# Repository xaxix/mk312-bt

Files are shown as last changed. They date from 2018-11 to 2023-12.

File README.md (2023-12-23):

# MK-312BT V1.3

Documentation at : http://tinyurl.com/mk312bt-info

Forum (for questions/discussion): https://metafetish.club ([Estim
Specific Category Here](https://metafetish.club/c/estim), but may not
include all estim messages)

## Board ordering instructions

Preferred board house is https://jlcpcb.com

You'll need 2 gerber zip files from the gerbers directory (click links below to download):

- [MK-312 V1.2 Front Panel](https://github.com/buttshock/mk312-bt/blob/master/gerbers/ZIP%20FILES/MK-312BT%20Front%20Panel%20V1.2%20Gerber.zip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)
- [MK-312 V1.3 Main Board](https://github.com/buttshock/mk312-bt/blob/master/gerbers/ZIP%20FILES/MK-312BT%20Main%20Boards%20V1.3%20Gerber.zip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)

**NOTE:** Order Front Panel and Main Board as seperate items (but they
can be in the same cart), due to difference in "Different Design"
setting. See below.

- Base Material: Standard "FR4"
- Layers: "2" Layer (should be detected when you upload the zip with the gerbers)
- Dimensions: (should be detected when you upload the zip with the gerbers)
- Quantity: No requirement, choose whatever you like
- Product Type: "Industrial/Consumer electronics"
- Different Design 
   - Main Boards: "2"
   - Front Panel: "1"
- Delivery Format: "Single PCB"
- Thickness: "1.6"
- PCB Color:
   - Main Boards: No requirement, choose whatever you like
   - Front Panel: Black is recommended, but not required. Choose whatever you like otherwise.
- Silkscreen: "White"
- Surface finish: "LeadFree HASL" or "HASL(with lead)
- Copper weight: 1oz
- Via Covering: Tented (?)
- Board Outline Tolerance: "+-0,2mm(Regular)"
- Confirm Production file: "No"
- Remove Order Number: "No"
- Flying Probe Test: "Fully Test"
- Gold fingers: "No"
- Castellated Holes: "No"
- Edge Plating: "No"
- PCB Remark:
   - Main Boards: V Score the Main Boards panel as indicated.
   - Front Panel: Place all Fab Markings (Serial Numbers/Date Codes) on the BOTTOM side of the front panel board.
   
## Board Assembly Instructions - IMPORTANT

1. Trim Potentiometer knobs to correct length if desired
2. Use black permanent marker to black out front panel hole walls if
   desired
3. Cut the tabs off of the base of the pots so the board sits flush
   with the display facade if desired
4. To correctly fit LCD - solder header to LCD board first. Next
   insert LCD panel into front panel daughter board. Then put screws
   on front panel facade and finger tighten M2.5 screws first. Adjust
   positions as needed so everything lines up and sits well. Finally
   solder LCD header to front panel daughter board.
5. Make sure Pin 32 (LED2) on the HC-05 module is actually soldered
   and making connection to the ZS-040 break out board or "Radio" LED
   may not function on the front panel
6. Be very careful not to bridge pins when soldering the LM 2941
   (U14). Apply heat to 1 pad only and carefully apply solder. If a
   bridge occurs - remove the IC, clean the pads throughly with flux
   and solder wick and then retry. Pins 2 and 3 can be bridged because
   they are both ground. Ensure that no other pins are bridged. Check
   with multimeter continuity tester for bridges before power on!
7. Make sure to check the orientation of all electrolytic caps. (+)
   indicates the positive and a solid white "|" indicates the negative.
8. **MAKE SURE YOUR POWER PLUG IS CENTER POSITIVE OR THINGS WILL GO
   BADLY.** If you fuck up and plug in a reversed polarity supply -
   replace electrolytic caps C1 and C4.
9. Please remember to adjust the LCD contrast potentiometer - if
   incorrectly set the unit and backlight will power on but the
   interface will not be displayed.
10. Place transformers with P facing the output jacks (yes we are
    using the transformers "backwards" if you follow orientation given
    in the transformer datasheet )
11. Trim pins of 4066 IC (U3) Socket on the front panel board flush
    before soldering so buttons can clear. If the buttons still
    interfere, carefully disassemble the button and cut off the bit of
    the plastic housing that interferes with the 4066 IC socket pins.
12. Using side cutters cut off the screw boss/screw mount on the case
    that touches/interferes with the ribbon cable socket on the
    display board.
13. The LCD display has metal retention tabs that may short the
    soldered leads of C43. When installing the display board ensure
    that this does not happen (shorten the capacitor leads and bend
    the offending metal tab out of the way if necessary
14. If Error 20 is encountered on first boot:
   - Check that all FETs and Transformers are turned in the correct direction
   - Check that resistors R35 and R46 are the correct 200k values
   - [See this thread on the message board](https://metafetish.club/t/mk-312bt-failure-20/)

## MK312-BT Firmware

1. We are using an external 8mhz crystal instead of the internal RC
   oscillator that the original uses. We need to set the fuses to
   enable this. 
   - LOW FUSE: 0xFF 
   - HIGH FUSE: 0xDC
2. A patched version of buttshock-et312-frankenbutt-f005 is
   recommended.
3. The firmware needs to be changed to replace the up/down arrows on
   the UI with left right arrows (this is because the LCD we use has a
   different character set)
4. Obtain or modify a copy of the firmware and flash the result onto
   the AVR.
5. If you don't want to use an external crystal - we need to set the
   calibration byte for the internal oscillator. If programming a
   blank chip you first need to read the calibration bytes of that
   part (i.e. using avrdude -t “dump calibration” the fourth byte is
   the calibration byte for 8MHz or use atmel studio to read the
   oscillator calibration byte). Then program that byte into 0x3fff in
   your firmware. These bytes will differ on different chips even from
   the same batch. The firmware reads that byte to set OSCCAL on
   startup. If the byte is inaccurate various problems and failures
   will occur related to timing, interrupts, and serial communication.
   Just use an external crystal dammit.

## MK312-BT Original Fab Notes

(These are the old fab notes from the repo, mostly kept here for
history sake. Ordering instructions above cover most of this.)

### Main Boards

1. V Score the Main Boards panel as indicated.
2. Main Boards has 2 board designs panelized on 1 panel.
3. Thickness is standard 1.6mm (0.063inches)
4. Board is 2 layers
5. HASL Finish - Pb Free Preferred if possible, otherwise Pb HASL is OK
6. 1oz copper
7. FR4 material
8. Main Boards : Green solder mask, White Silkscreen (silkscreen BOTH top and bottom sides)
9. ITAR : NO
10. IPC-A-610 - Class2 (If possible - otherwise ignore)
11. Main Board Dimensions : (193.04mm x 104.14mm) or (7.600 inches x 4.100 inches) 

### Front Panel Boards

1. Place all Fab Markings (Serial Numbers/Date Codes) on the BOTTOM side of the front panel board. 
2. Thickness is standard 1.6mm (0.063inches)
3. Board is 2 layers
4. HASL Finish - Pb Free Preferred if possible, otherwise Pb HASL is OK
5. 1oz copper
6. FR4 material
7. Front Panel Boards : Black Solder Mask, While Silkscreen
8. ITAR : NO
9. IPC-A-610 - Class2 (If possible - otherwise ignore)
10. Front Panel Board Dimensions :  (196.85mm x 58.72mm) or (7.750inches x 2.312inches) 

## Bluetooth Serial Configuration

Refer to
[https://www.itead.cc/wiki/Serial_Port_Bluetooth_Module_(Master/Slave)_:_HC-05](https://www.itead.cc/wiki/Serial_Port_Bluetooth_Module_(Master/Slave)_:_HC-05)
for more information.

```
// Test command to check if we are communicating (expect to receive OK)
AT

//Name the module
AT+NAME=MK-312BT 

//Set baud rate to be same as the ATMEGA16
AT+UART=19200,0,0

//Set the pairing password
AT+PSWD=1234

//Set the LED Indicator polarity (1 = High Drive 0 = Low Drive)
AT+POLAR=1,1

// Reduce power consumption by increasing the scan interval. Without
// this it consumes ~43mA when not connected and causes the 5v regulator
// to get toasty (but still within operational temp range)
AT+IPSCAN=1024,1,1024,1 
```

To do this automatically:
1. Solder Pin32 of the HC05 module (See [bluetooth/HC05PINOUT.PNG](https://github.com/buttshock/mk312-bt/blob/master/bluetooth_conf/HC05PINOUT.png) for reference)
2. Flash the included bin file onto the ATMEGA16
3. Plug the HC-05 bluetooth radio into the board (ensure pin 32 is
   soldered to the carrier board)
4. Place HC-05 in command mode by holding down the button on the HC-05
   module, power up MK-312BT and release button after 2 seconds. LEDs
   on HC-05 will blink slowly (0.5 Hz) to indicate command mode.
5. Watch GUI until it says the HC-05 configuration is finished and
   flash normal firmware back on to the ATMEGA16
6. If program stops on "Communicating with HC-05" make sure OSCCAL
   value for 8 MHz R/C position is copied to &H3FFF of bin location or
   use external 8 MHz crystal with appropriate fuse bits set (FFS use
   the external crystal)

## 3D Printable Case

STL files for a 3D printable case for the MK312 are available in the
case/ directory. For hardware, this case requires:

- 4 M2.5x20 screws
- up to 3 M2.5x5 screws
- some dampening for the battery (double sided foam tape may work)

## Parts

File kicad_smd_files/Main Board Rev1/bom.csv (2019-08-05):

Item | Qty | Reference(s) | Value | LibPart | Footprint | Datasheet | Allied Price/Stock | Allied_Number | Description | Height | Manufacturer_Name | Manufacturer_Part_Number | Mouser Part Number | Mouser Price/Stock | Notes | RS Part Number | RS Price/Stock
1 | 1 | C1 | 10uF | Device:C_Small | Capacitor_SMD:C_0805_2012Metric |  |  |  |  |  | Taiyo Yuden | TMK212BBJ106MG-T | 963-TMK212BBJ106MG-T
2 | 27 | C2, C3, C6, C7, C8, C9, C10, C11, C17, C18, C19, C20, C24, C31, C34, C35, C36, C37, C40, C41, C42, C43, C44, C45, C46, C47, C48 | 0.1uF | Device:C_Small | Capacitor_SMD:C_0402_1005Metric | https://www.mouser.com/datasheet/2/281/murata_03122018_GCM_Series-1310150.pdf |  |  |  |  | Murata | GCM155R71C104JA55D | 81-GCM155R71C104JA5D
3 | 2 | C4, C5 | 100uF | Device:CP1 | Capacitor_SMD:C_Elec_6.3x7.7 | https://www.mouser.com/datasheet/2/315/ABA0000C1240-1130326.pdf |  |  |  |  | Panasonic | EEE-HC1C101XP | 667-EEE-HC1C101XP
4 | 2 | C12, C14 | 470uF | Device:CP1 | Capacitor_SMD:C_Elec_8x10.2 | https://www.mouser.com/datasheet/2/315/ABA0000C1181-947564.pdf |  |  |  |  | Panasonic | EEE-FK1C471P | 667-EEE-FK1C471P
5 | 1 | C13 | 10uF | Device:CP1 | Capacitor_SMD:C_Elec_4x5.8 | https://www.mouser.com/datasheet/2/315/ABA0000C1181-947564.pdf |  |  |  |  | Panasonic | EEE-FK1C100R | 667-EEE-FK1C100R
6 | 2 | C15, C16 | 18pF | Device:C_Small | Capacitor_SMD:C_0402_1005Metric | https://www.mouser.com/datasheet/2/281/GCM1555C1H180FA16-01-1064431.pdf |  |  |  |  | Murata | GCM1555C1H180FA16J | 81-GCM1555C1H180FA6J
7 | 11 | C21, C22, C23, C25, C26, C27, C28, C29, C30, C38, C39 | 1uF | Device:C_Small | Capacitor_SMD:C_0402_1005Metric | https://www.mouser.com/datasheet/2/281/murata_03052018_GRM_Series_1-1310166.pdf |  |  |  |  | Murata | GRM155R61C105MA12D | 81-GRM155R61C105MA2D
8 | 2 | C32, C33 | 1nF | Device:C_Small | Capacitor_SMD:C_0402_1005Metric | https://www.mouser.com/datasheet/2/281/murata_03122018_GCM_Series-1310150.pdf |  |  |  |  | Murata | GCM1555C1H102JA16J | 81-GCM1555C1H102JA6J
9 | 1 | C49 | 2.2uF | Device:C_Small | Capacitor_SMD:C_0603_1608Metric |  |  |  |  |  | KEMET | C0603C225K4PACTU | 80-C0603C225K4P
10 | 2 | D1, D2 | GF1G-E3/67A | Diode:1N4004 | mk312-smd-footprints:DO-214BA | http://www.rectron.com/public/product_datasheets/fm4001w-fm4007w.pdf |  |  | Rectifiers 1A, 400V | 2.31 | Rectron | FM4004W-W | 583-FM4004W-W | https://www.mouser.com/Search/Refine.aspx?Keyword=583-FM4004W-W
11 | 2 | D3, D4 | 1N4148W-E3-08 | Device:D | Diode_SMD:D_SOD-123 | https://www.mouser.com/datasheet/2/427/1n4148w-240387.pdf |  |  |  |  | Vishay | 1N4148W-E3-08 | 78-1N4148W-E3-08
12 | 1 | F1 | 1A Polyfuse | Device:Polyfuse | Fuse:Fuse_2920_7451Metric | https://www.mouser.com/datasheet/2/643/0ZCF_Nov2016-1133542.pdf |  |  |  |  | Bel Fuse | 0ZCF0100AF2A | 530-0ZCF0100AF2A
13 | 6 | H1, H2, H3, H4, H5, H6 | MountingHole | Mechanical:MountingHole | MountingHole:MountingHole_2.7mm_M2.5 | ~
14 | 2 | H7, H8 | MountingHole | Mechanical:MountingHole | MountingHole:MountingHole_3.5mm | ~
15 | 1 | IC1 | LMS8117ADTX-ADJ | Regulator_Linear:NCP1117-ADJ_TO252 | Package_TO_SOT_SMD:TO-252-2 | www.ti.com/lit/ds/symlink/lms8117a.pdf |  |  |  |  | Texas Instruments | LMS8117ADTX-ADJ | 926-LS8117ADTXADJNPB
16 | 1 | IC2 | L7805CV | Regulator_Linear:L7805 | Package_TO_SOT_THT:TO-220-3_Vertical | https://www.mouser.com/datasheet/2/389/l78-974043.pdf | http://www.alliedelec.com/stmicroelectronics-l7805abd2t-tr/70407657/ | 70407657 |  | 4.6 | STMicroelectronics | L7805CV | 511-L7805CV | https://www.mouser.com/Search/Refine.aspx?Keyword=511-L7805ABD2T-TR |  | 7931342P | http://uk.rs-online.com/web/p/products/7931342P
17 | 2 | IC3, IC4 | L7809ABV | Regulator_Linear:L7809 | Package_TO_SOT_THT:TO-220-3_Vertical | https://www.mouser.com/datasheet/2/389/l78-974043.pdf |  |  |  |  | STMicroelectronics | L7809ABV | 511-L7809ABV | https://www.mouser.com/Search/Refine.aspx?Keyword=511-L7809ABD2T-TR
18 | 2 | IC5, IC6 | SI4435FDY-T1-GE3 | SamacSys_Parts:SI4435FDY-T1-GE3 | mk312-smd-footprints:SOIC127P600X175-8N | http://www.vishay.com/docs/75339/si4435fdy.pdf |  |  | MOSFET -30V Vds 20V Vgs SO-8 | 1.75 | Vishay | SI4435FDY-T1-GE3 | 78-SI4435FDY-T1-GE3 | https://www.mouser.com/Search/Refine.aspx?Keyword=78-SI4435FDY-T1-GE3
19 | 1 | J1 | Barrel_Jack_MountingPin | Connector:Barrel_Jack_Switch | Connector_BarrelJack:BarrelJack_Horizontal | https://www.mouser.com/datasheet/2/670/pj-002a-1312176.pdf |  |  |  |  | CUI | PJ-002A | 490-PJ-002A
20 | 1 | J2 | +12V Battery | Connector_Generic:Conn_01x02 | Connector_AMASS:AMASS_XT30U-M_1x02_P5.0mm_Vertical | ~
21 | 1 | J3 | Conn_02x03_Odd_Even | Connector_Generic:Conn_02x03_Odd_Even | Connector_PinHeader_2.54mm:PinHeader_2x03_P2.54mm_Vertical | https://www.mouser.com/datasheet/2/418/NG_CD_103328_P5-1229876.pdf |  |  |  |  | TE Connectivity / AMP | 4-103328-2 | 571-4-103328-2
22 | 1 | J4 | RADIO INTERFACE | Connector_Generic:Conn_01x06 | Connector_PinHeader_2.54mm:PinHeader_1x06_P2.54mm_Vertical | https://www.mouser.com/datasheet/2/527/slw-1370256.pdf |  |  |  |  | Samtec | SLW-106-01-G-S | 200-SLW10601GS
23 | 1 | J5 | MIC INPUT | Connector:AudioJack3_SwitchTR | mk312-smd-footprints:SJ13515SMTTR | https://www.mouser.com/datasheet/2/670/sj1-351x-smt_series-1312823.pdf |  |  |  |  | CUI | SJ1-3515-SMT-TR | 490-SJ1-3515-SMT-TR
24 | 1 | J6 | LINE INPUT | Connector:AudioJack3_SwitchTR | mk312-smd-footprints:SJ13515SMTTR | https://www.mouser.com/datasheet/2/670/sj1-351x-smt_series-1312823.pdf |  |  |  |  | CUI | SJ1-3515-SMT-TR | 490-SJ1-3515-SMT-TR
25 | 1 | J7 | REMOTE INPUT | Connector:AudioJack3_SwitchTR | mk312-smd-footprints:SJ13515SMTTR | https://www.mouser.com/datasheet/2/670/sj1-351x-smt_series-1312823.pdf |  |  |  |  | CUI | SJ1-3515-SMT-TR | 490-SJ1-3515-SMT-TR
26 | 1 | J8 | LINK INPUT | Connector:AudioJack3_SwitchTR | mk312-smd-footprints:SJ13515SMTTR | https://www.mouser.com/datasheet/2/670/sj1-351x-smt_series-1312823.pdf |  |  |  |  | CUI | SJ1-3515-SMT-TR | 490-SJ1-3515-SMT-TR
27 | 1 | J9 | OUTPUT A | Connector:AudioJack3_SwitchTR | mk312-smd-footprints:SJ13515SMTTR | https://www.mouser.com/datasheet/2/670/sj1-351x-smt_series-1312823.pdf |  |  |  |  | CUI | SJ1-3515-SMT-TR | 490-SJ1-3515-SMT-TR
28 | 1 | J10 | OUTPUT B | Connector:AudioJack3_SwitchTR | mk312-smd-footprints:SJ13515SMTTR | https://www.mouser.com/datasheet/2/670/sj1-351x-smt_series-1312823.pdf |  |  |  |  | CUI | SJ1-3515-SMT-TR | 490-SJ1-3515-SMT-TR
29 | 1 | J11 | Conn_01x24_Male | Connector:Conn_01x24_Male | mk312-smd-footprints:HFW24S-2STE1LF | https://www.mouser.com/datasheet/2/18/hfw_s-2ste1lf-1365432.pdf |  |  |  |  | Amphenol FCI | HFW24S-2STE1LF | 649-HFW24S-2STE1LF
30 | 1 | J12 | Conn_01x24_Male | mk312:Conn_01x24_Male_Power | mk312-smd-footprints:HFW24S-2STE1LF | https://www.mouser.com/datasheet/2/18/hfw_s-2ste1lf-1365432.pdf |  |  |  |  | Amphenol FCI | HFW24S-2STE1LF | 649-HFW24S-2STE1LF
31 | 1 | J13 | Conn_01x04 | Connector_Generic:Conn_01x04 | Connector_JST:JST_XH_B4B-XH-A_1x04_P2.50mm_Vertical | ~
32 | 1 | JP2 | +5V | Connector_Generic:Conn_01x02 | Connector_PinHeader_2.54mm:PinHeader_1x02_P2.54mm_Vertical | https://www.mouser.com/datasheet/2/418/NG_CD_146285_J-649398.pdf |  |  |  |  | TE Connectivity | 5-146285-2 | 571-5-146285-2
33 | 1 | JP3 | AUX LINE IN | Connector_Generic:Conn_01x04 | Connector_PinHeader_2.54mm:PinHeader_1x04_P2.54mm_Vertical | https://www.mouser.com/datasheet/2/418/NG_CD_146285_J-649398.pdf |  |  |  |  | TE Connectivity | 5-146285-2 | 571-5-146285-2
34 | 1 | JP4 | A RING | Connector_Generic:Conn_01x02 | Connector_PinHeader_2.54mm:PinHeader_1x02_P2.54mm_Vertical | https://www.mouser.com/datasheet/2/418/NG_CD_146285_J-649398.pdf |  |  |  |  | TE Connectivity | 5-146285-2 | 571-5-146285-2
35 | 1 | JP5 | B RING | Connector_Generic:Conn_01x02 | Connector_PinHeader_2.54mm:PinHeader_1x02_P2.54mm_Vertical | https://www.mouser.com/datasheet/2/418/NG_CD_146285_J-649398.pdf |  |  |  |  | TE Connectivity | 5-146285-2 | 571-5-146285-2
36 | 1 | LCD1 | NHD-C0216AZ-FSW-GBW | mk312:NHD-C0216AZ-FSW-GBW | mk312-smd-footprints:NHD-C0216AZ-FSW-GBW | https://www.mouser.com/datasheet/2/291/NHD-C0216AZ-FSW-GBW-31543.pdf |  |  |  |  | Newhaven Display | NHD-C0216AZ-FSW-GBW | 763-C0216AZ-FSW-GBW
37 | 1 | LED1 | POWER | Device:LED | mk312-smd-footprints:LED_Cree-PLCC4_3.2x2.8mm_CCW | https://www.mouser.com/datasheet/2/90/1410-CLM2D-GPC-BPC-1275496.pdf |  |  |  |  | Cree | CLM2D-BPC-CWBYA453 | 941-CLM2DBPCCWBYA453
38 | 1 | LED2 | OUTPUT B | Device:LED | mk312-smd-footprints:LED_Cree-PLCC4_3.2x2.8mm_CCW | https://www.mouser.com/datasheet/2/90/1410-CLM2D-GPC-BPC-1275496.pdf |  |  |  |  | Cree | CLM2D-BPC-CWBYA453 | 941-CLM2DBPCCWBYA453
39 | 1 | LED3 | OUTPUT A | Device:LED | mk312-smd-footprints:LED_Cree-PLCC4_3.2x2.8mm_CCW | https://www.mouser.com/datasheet/2/90/1410-CLM2D-GPC-BPC-1275496.pdf |  |  |  |  | Cree | CLM2D-BPC-CWBYA453 | 941-CLM2DBPCCWBYA453
40 | 1 | LED4 | STATE | Device:LED | mk312-smd-footprints:LED_Cree-PLCC4_3.2x2.8mm_CCW | https://www.mouser.com/datasheet/2/90/1410-CLM2D-GPC-BPC-1275496.pdf |  |  |  |  | Cree | CLM2D-BPC-CWBYA453 | 941-CLM2DBPCCWBYA453
41 | 2 | Q1, Q2 | MMBT3904-7-F | Transistor_BJT:2N3904 | Package_TO_SOT_SMD:SOT-23 | https://www.mouser.com/datasheet/2/115/ds30036-41708.pdf |  |  |  |  | Diodes Incorporated | MMBT3904-7-F | 621-MMBT3904-F
42 | 4 | Q3, Q5, Q6, Q8 | IRFR9024NTRPBF | mk312:IRL520N | Package_TO_SOT_SMD:TO-252-2 | https://www.mouser.com/datasheet/2/196/irfr9024npbf-1228513.pdf |  |  |  |  | Infineon | IRFR9024NTRPBF | 942-IRFR9024NTRPBF
43 | 2 | Q4, Q7 | IRLR120NTRPBF | mk312:IRF9Z24N | Package_TO_SOT_SMD:TO-252-2 | https://www.mouser.com/datasheet/2/196/irlr120npbf-1228003.pdf |  |  |  |  | Infineon | IRLR120NTRPBF | 942-IRLR120NTRPBF
44 | 11 | R1, R14, R15, R16, R19, R64, R67, R68, R69, R70, R71 | 1K | Device:R_US | Resistor_SMD:R_0603_1608Metric | https://www.mouser.com/datasheet/2/315/AOA0000C331-1141874.pdf |  |  |  |  | Panasonic | ERJ-PA3F1001V | 667-ERJ-PA3F1001V
45 | 1 | R2 | 110 | Device:R_US | Resistor_SMD:R_0603_1608Metric | https://www.mouser.com/datasheet/2/315/AOA0000C331-1141874.pdf |  |  |  |  | Panasonic | ERJ-PA3F1100V | 667-ERJ-PA3F1100V
46 | 22 | R3, R21, R22, R30, R31, R37, R38, R39, R41, R42, R43, R44, R45, R46, R47, R49, R51, R52, R53, R54, R55, R56 | 100K | Device:R_US | Resistor_SMD:R_0603_1608Metric | https://www.mouser.com/datasheet/2/315/AOA0000C331-1141874.pdf |  |  |  |  | Panasonic | ERJ-PA3F1003V | 667-ERJ-PA3F1003V
47 | 6 | R4, R23, R24, R27, R32, R33 | 20K | Device:R_US | Resistor_SMD:R_0603_1608Metric | https://www.mouser.com/datasheet/2/315/AOA0000C331-1141874.pdf |  |  |  |  | Panasonic | ERJ-PA3F2002V | 667-ERJ-PA3F2002V
48 | 8 | R5, R25, R57, R58, R59, R60, R61, R62 | 10K | Device:R_US | Resistor_SMD:R_0603_1608Metric | https://www.mouser.com/datasheet/2/315/AOA0000C331-1141874.pdf |  |  |  |  | Panasonic | ERJ-PA3F1002V | 667-ERJ-PA3F1002V
49 | 1 | R6 | 3.3K | Device:R_US | Resistor_SMD:R_0603_1608Metric | https://www.mouser.com/datasheet/2/315/AOA0000C331-1141874.pdf |  |  |  |  | Panasonic | ERJ-PA3F3301V | 667-ERJ-PA3F3301V
50 | 4 | R7, R8, R9, R10 | 390 | Device:R_US | Resistor_SMD:R_0603_1608Metric | https://www.mouser.com/datasheet/2/315/AOA0000C331-1141874.pdf |  |  |  |  | Panasonic | ERJ-PA3F3900V | 667-ERJ-PA3F3900V
51 | 1 | R11 | 130 | Device:R_US | Resistor_SMD:R_0603_1608Metric |  |  |  |  |  | Yageo | RC0603FR-07130RL | 603-RC0603FR-07130RL
52 | 3 | R12, R13, R18 | 1.5K | Device:R_US | Resistor_SMD:R_0603_1608Metric | https://www.mouser.com/datasheet/2/315/AOA0000C331-1141874.pdf |  |  |  |  | Panasonic | ERJ-PA3F1501V | 667-ERJ-PA3F1501V
53 | 2 | R17, R20 | 2.2K | Device:R_US | Resistor_SMD:R_0603_1608Metric | https://www.mouser.com/datasheet/2/315/AOA0000C331-1141874.pdf |  |  |  |  | Panasonic | ERJ-PA3F2201V | 667-ERJ-PA3F2201V
54 | 2 | R26, R29 | 4.7K | Device:R_US | Resistor_SMD:R_0603_1608Metric | https://www.mouser.com/datasheet/2/315/AOA0000C331-1141874.pdf |  |  |  |  | Panasonic | ERJ-PA3F4701V | 667-ERJ-PA3F4701V
55 | 5 | R28, R34, R35, R36, R65 | 1M | Device:R_US | Resistor_SMD:R_0603_1608Metric | https://www.mouser.com/datasheet/2/315/AOA0000C331-1141874.pdf |  |  |  |  | Panasonic | ERJ-PA3F1004V | 667-ERJ-PA3F1004V
56 | 1 | R40 | 0.5R 1/2W | Device:R_US | Resistor_SMD:R_2010_5025Metric | https://www.mouser.com/datasheet/2/427/wsl-9-1128311.pdf |  |  |  |  | Vishay | WSL2010R5000FEA | 71-WSL2010R5000FEA
57 | 2 | R48, R50 | 200K | Device:R_US | Resistor_SMD:R_0603_1608Metric | https://www.mouser.com/datasheet/2/315/AOA0000C331-1141874.pdf |  |  |  |  | Panasonic | ERJ-PA3F2003V | 667-ERJ-PA3F2003V
58 | 2 | R63, R66 | 5.1K | Device:R_US | Resistor_SMD:R_0603_1608Metric | ~ |  |  |  |  | Yageo | RC0603FR-075K1L | 603-RC0603FR-075K1L
59 | 1 | R72 | 51 | Device:R_US | Resistor_SMD:R_0603_1608Metric | ~ |  |  |  |  | Yageo | RC0603FR-0751RL | 603-RC0603FR-0751RL
60 | 1 | S1 | POWER | mk312:SW_SPDT_POWER | mk312-smd-footprints:E-Switch_M7_SPDT | https://www.mouser.com/datasheet/2/140/100-1079940.pdf |  |  |  |  | E-Switch | 100SP1T2B4M7RE | 612-100-A2472
61 | 1 | SW2 | LEFT/DOWN | Switch:SW_Push | mk312-smd-footprints:E-Switch_Tactile_TL1105 | https://www.mouser.com/datasheet/2/140/XP0214A-1511152.pdf |  |  |  |  | E-Switch | TL1105SPF160Q | 612-TL1105SP
62 | 1 | SW3 | OK | Switch:SW_Push | mk312-smd-footprints:E-Switch_Tactile_TL1105 | https://www.mouser.com/datasheet/2/140/XP0214A-1511152.pdf |  |  |  |  | E-Switch | TL1105SPF160Q | 612-TL1105SP
63 | 1 | SW4 | RIGHT/UP | Switch:SW_Push | mk312-smd-footprints:E-Switch_Tactile_TL1105 | https://www.mouser.com/datasheet/2/140/XP0214A-1511152.pdf |  |  |  |  | E-Switch | TL1105SPF160Q | 612-TL1105SP
64 | 1 | SW5 | MENU | Switch:SW_Push | mk312-smd-footprints:E-Switch_Tactile_TL1105 | https://www.mouser.com/datasheet/2/140/XP0214A-1511152.pdf |  |  |  |  | E-Switch | TL1105SPF160Q | 612-TL1105SP
65 | 2 | TR1, TR2 | 42TL004 | mk312:42TL004 | mk312-smd-footprints:42TL | https://www.mouser.com/datasheet/2/449/Yuetone_XC-600127-1212403.pdf |  |  |  |  | Xicon | 42TL004-RC | 42TL004-RC
66 | 1 | U1 | ATmega16-16AU | MCU_Microchip_ATmega:ATmega16-16AU | Package_QFP:TQFP-44_10x10mm_P0.8mm | http://ww1.microchip.com/downloads/en/DeviceDoc/doc2466.pdf |  |  |  |  | Atmel | ATMEGA16-16AU | 556-ATMEGA16-16AU
67 | 1 | U2 | MCP6L01U | estim_parts:MCP6L01U | Package_TO_SOT_SMD:SOT-23-5 | https://www.mouser.com/datasheet/2/268/22140a-71218.pdf |  |  |  |  | Microchip | MCP6L01UT-E/OT | 579-MCP6L01UT-E/OT
68 | 1 | U3 | CD4066B | 4xxx:4066 | Package_SO:SOIC-14_3.9x8.7mm_P1.27mm | http://www.ti.com/lit/ds/symlink/cd4066b.pdf |  |  |  |  | Texas Instruments | CD4066BM96 | 595-CD4066BM96
69 | 1 | U4 | SP232E | Interface_UART:MAX232 | Package_SO:SOIC-16_3.9x9.9mm_P1.27mm | https://www.mouser.com/datasheet/2/146/SP202E-SP232E-SP233E-SP310E-SP312E-536253.pdf |  |  |  |  | MaxLinear | SP232EEN-L/TR | 701-SP232EEN-L/TR
70 | 1 | U5 | S-8254A | estim_parts:S-8254A | Package_SO:TSSOP-16_4.4x5mm_P0.65mm | https://www.mouser.com/datasheet/2/360/S8254A_E-1365929.pdf |  |  |  |  | ABLIC | S-8254AAMFT-TB-U | 628-S-8254AAMFT-TB-G
71 | 1 | U6 | LM324N | Amplifier_Operational:LM324 | Package_SO:SOIC-14_3.9x8.7mm_P1.27mm | http://www.ti.com/lit/ds/symlink/lm324.pdf |  |  |  |  | Texas Instruments | LM324DR | 595-LM324DR
72 | 1 | U7 | LM358N | Amplifier_Operational:LM358 | Package_SO:SOIC-8_3.9x4.9mm_P1.27mm | http://www.ti.com/lit/ds/symlink/lm358a.pdf |  |  |  |  | Texas Instruments | LM358ADR | 595-LM358ADR
73 | 1 | U8 | LTC1661 | mk312:LTC1661 | Package_SO:MSOP-8_3x3mm_P0.65mm | https://www.analog.com/media/en/technical-documentation/data-sheets/1661fb.pdf |  |  |  |  | Analog Devices Inc. | LTC1661CMS8#PBF | 584-LTC1661CMS8#PBF |  | This chip is expensive nearly $4 a piece, could be an alternate DAC
74 | 1 | VR1 | MULTI-ADJ | mk312:R_POT_DUAL_CHASSIS_US | mk312-smd-footprints:Potentiometer_Alps_RK09K_Dual_Vertical | https://www.mouser.com/datasheet/2/15/RK09K-771158.pdf |  |  |  |  | Alps | RK09K12C0A8K | 688-RK09K12C0A8K
75 | 1 | VR2 | LEVEL A | mk312:R_POT_CHASSIS_US | mk312-smd-footprints:Potentiometer_Alps_RK09K_Single_Vertical | https://www.mouser.com/datasheet/2/15/RK09K-771158.pdf |  |  |  |  | Alps | RK09D1130A1N | 688-RK09D1130A1N
76 | 1 | VR3 | LEVEL B | mk312:R_POT_CHASSIS_US | mk312-smd-footprints:Potentiometer_Alps_RK09K_Single_Vertical | https://www.mouser.com/datasheet/2/15/RK09K-771158.pdf |  |  |  |  | Alps | RK09D1130A1N | 688-RK09D1130A1N
77 | 1 | VR4 | LCD CONTRAST | Device:R_POT_TRIM_US | Potentiometer_SMD:Potentiometer_Bourns_TC33X_Vertical | https://www.mouser.com/datasheet/2/54/c33-778219.pdf |  |  |  |  | Bourns | TC33X-2-103E | 652-TC33X-2-103E
78 | 1 | XTAL1 | 8.0 MHz | Device:Crystal_Small | Crystal:Crystal_SMD_HC49-SD | https://www.mouser.com/datasheet/2/741/LFXTAL020423Reel-940439.pdf |  |  |  |  | IQD | LFXTAL020423Reel | 449-LFXTAL020423REEL

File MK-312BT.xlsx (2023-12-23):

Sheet: INFO
MK-312 BT V1.3R Information
Github Project Home: https://github.com/buttshock/mk312-bt
Message Boards: https://metafetish.club
Discord (Chat): https://discord.buttplug.io
Construction Videos: https://www.youtube.com/playlist?list=PLDZBOOe-bdwPYMWLqG2gFVGe-te_oV037
About
INFO is this Google Sheet - the latest copy of this document lives at http://tinyurl.com/mk312bt-info or https://goo.gl/Ia0wMW
FULLBOM consists of all items - sorted for sanity. Enter the number of units you want to produce in the top row and it will math for you.
MOUSERBOM1 contains items in FULL_BOM available from mouser and we select the "recommended" options . This BOM is for 1 UNIT.
NONMOUSER is a list of all the parts you cant get from Mouser with links to where you can get them from
RAWBOM is the output Eagle generates for the V1.1 schematic. This is used for cross checking the other documents.
MK-312BT V1.3R - How to Order Parts
1) Order the PCB from the gerber files https://goo.gl/um2Wv1 or http://tinyurl.com/y7p2b9hx
2) Order 1 set of the Mouser Parts from this Mouser Project: https://tinyurl.com/yagb87b2
3) Order 1 set of Digikey Parts from this Digikey cart (DAC, Ribbon Cable) : https://tinyurl.com/ybprysx7
4) Order the case from Allied Electronics : http://tinyurl.com/m8vhmxb
5) Order the hardware parts from McMaster (Wire, Heat Shrink Tubing, sheet metal screw, socket head screw and m2.5 nut (see NONMOUSER sheet tab of this document)
6) (Optionally) order the bluetooth radio from Amazon : http://amzn.to/2l0UEoj
7) If parts on Digikey OR Mouser are showing as "Out of Stock/Backordered - consult FULLBOM and MOUSERBOM1 sheet tabs of this document for replacement parts"
8) (Optional) You will need strong double sided tape to mount the battery - 3M VHB is recommended - http://amzn.to/2nTkawE
9) Note - it is cheaper to buy the following minimum quantities of parts : R55 - 10, R53 - 10, R2 - 10, R18 - 10, R38 - 10, R1A - 10, R14 - 10, R12 - 10, D2 - 10, R35 - 10, R11 - 10, R6 - 10, R7 - 10, R13 - 10
MK-312BT V1.3R - Hardware Improvements over original ET-312B
1) Line input modified for matched frequency and level response on left and right channels.
2) Link I/O circuitry replaced with MAX-232CPE For better compatibility (True RS-232 Levels)
3) Provisions for Bluetooth radio, Radio takes over Link I/O when nothing is in the jack
4) New one piece front panel design where LCD, buttons, potentiometers, and LEDs are on the sub panel. Jacks and power switch on mainboard. Cleaner looking design with controls and jacks on 3/4" centers
5) Remote input added to facilitate DC response into B channel without compromising line audio input characteristics. Tip is voltage coming from remote 0-2 volts, Ring supplies 2 volts from a resistor divider internal to the unit. Sleeve is ground. The Remote is meant for the Audio 1 & 2 modes. External potentiometer and push button recommended for remote. Other SPST type of items can be used such as motion detectors with dry contact output or mercury switches.
6) Support for tri polar (+, GND, -) toys on the output channels
7) Taps for +5V/+12V on power lines - Useful for embedding MP3 Players, for instance.
MK-312BT Hardware Jumper Settings
1) JP6 and JP7 [DISABLED BY DEFAULT]
Enabling JP6 and JP7 allow the use of tripolar (+, GND, -) toys on the corresponding channels by connecting the center tap of the transformer to the stereo jack
WARNING : ENABLING JP6 and JP7 will cause mono plug toys to short the transformer !!
MK-312BT Hardware Assembly Notes / Tips - PLEASE READ -
1) Trim Potentiometer knobs to correct length if desired
2) Use black permanent marker to black out front panel hole walls if desired
3) Cut the tabs off of the base of the pots so the board sits flush with the display facade if desired
4) To correctly fit LCD - solder header to LCD board first. Next insert LCD panel into front panel daughter board. Then put screws on front panel facade and finger tighten M2.5 screws first. Adjust positions as needed so everything lines up and sits well. Finally solder LCD header to front panel daughter board.
5) Make sure Pin 32 (LED2) on the HC-05 module is actually soldered and making connection to the ZS-040 break out board or "Radio" LED may not function on the front panel
6) Be very careful not to bridge pins when soldering the LM 2941 (U14). Apply heat to 1 pad only and carefully apply solder. If a bridge occurs - remove the IC, clean the pads throughly with flux and solder wick and then retry. Pins 2 and 3 can be bridged because they are both ground. Ensure that no other pins are bridged. Check with multimeter continuity tester for bridges before power on!
8) Make sure to check the orientation of all electrolytic caps. (+) indicates the positive and a solid white "|" indicates the negative .
9) MAKE SURE YOUR POWER PLUG IS CENTER POSITIVE OR THINGS WILL GO BADLY. If you fuck up and plug in a reversed polarity supply - replace electrolytic caps C1 and C4.
10) Please remember to adjust the LCD contrast potentiometer - if incorrectly set the unit and backlight will power on but the interface will not be displayed.
11) Place transformers with P facing the output jacks (yes we are using the transformers "backwards" if you follow orientation given in the transformer datasheet )
12)Trim pins of 4066 IC (U3) Socket on the front panel board flush before soldering so buttons can clear. If the buttons still interfere, carefully disassemble the button and cut off the bit of the plastic housing that interferes with the 4066 IC socket pins.
13) Getting the buttons to align is a pain (they will foul on things if not perfectly aligned). The best way is to fully assemble the front panel without worrying too much about the alignment or the fouling and then when the panel is fully together, go around the button a few times reheating a couple of its pins at a time ( either with a wide knife tip, with two irons , or with hot air - this will allow the buttons to "settle" into place nicely
14) Using side cutters cut off the screw boss/screw mount on the case that touches/interferes with the ribbon cable socket on the display board.
15) The LCD display has metal retention tabs that may short the soldered leads of C43. When installing the display board ensure that this does not happen (shorten the capacitor leads and bend the offending metal tab out of the way if necessary. Optionally - Do Not Fit C43 - it is not entirely necessary.
Changes made in buttshock-et312-frankenbutt f005 over original ET 312B V1.5/V1.6 firmware https://git.io/vMoHG
F005 Patches the following in addition to the stock firmware
1) changeversion: changes startup message from v1.6 to f005
2) unifyboxes: allow 1.5 and 1.6 boxes to share the same firmware
3) removerandomxor: box will always pick 0 as it's xor communication key
4) serialdumpmemory: box will allow serial to dump more of the flash memory on request
5) fixknobscaling: A and B levels now display smoothly 0-99 with no missing numbers
6) newmenu; adds a new sub menu "More Options", moves Link Slave to that menu
7) hookmain: adds a new mode "Random 3" kind of a combination of torment and random1 to the new options menu, adds a new mode "Random 4" which turns on with a random mode for 40ish seconds, then off for 20ish seconds
Modifying and Flashing Firmware onto MK312-BT
1) We are using an external 8mhz crystal instead of the internal RC oscillator that the original uses. We need to set the fuses to enable this. LOW FUSE : 0xFF HIGH FUSE : 0xDC
2) (Recommended if Bluetooth Module is used) Before flashing the main firmware - install the bluetooth radio and set it up per this guide /firmware script : https://git.io/vHnNv
3) A patched version of buttshock-et312-frankenbutt-f005 is recommended .
4) The firmware needs to be changed to replace the up/down arrows on the UI with left right arrows (this is because the LCD we use has a different character set)
5) Obtain or modify a copy of the firmware and flash the result onto the AVR.
6) If you dont want to use an external crystal - we need to set the calibration byte for the internal oscillator. If programming a blank chip you first need to read the calibration bytes of that part (i.e. using avrdude -t “dump calibration” the fourth byte is the calibration byte for 8MHz or use atmel studio to read the oscillator calibration byte). Then program that byte into 0x3fff in your firmware. These bytes will differ on different chips even from the same batch. The firmware reads that byte to set OSCCAL on startup. If the byte is inaccurate various problems and failures will occur related to timing, interrupts, and serial communication. Just use an external crystal dammit.
7) In order to reduce display flicker on MK312-BT go to offset 0x45E and change it from 0xAE 0x70 to 0xAF 0x73
Errata and and Changes made from V1.0 to V1.1
1) C25 and C27 are mislabeled on the board, 1000pF is the correct value (FIXED)
2) R20 and R21 are mislabeled on the board, 100K is the correct value (FIXED)
3) R14 and R15 are mislabeled on the board, 1K is the correct value (FIXED)
4) R20 and R21 are mislabeled on the board, 20K is the correct value (FIXED)
5) Do not populate R9 100K (FIXED)
6) Do not populate R1B 12K (FIXED)
Errata and and Changes made from V1.1 to V1.2
1) Fixed routing error on display board. (FIXED)
2) Removed JP3 because pointless. (FIXED)
3) Changed size of electrolytics to make things fit a bit nicer. (FIXED)
Errata and and Changes made from V1.2 to V1.3
1) LM 2941 footprint to make it easier to solder without bridging (PENDING)
2) Move 4066 IC to better place. (DONE)
3) Fix silkscreen "+" on electrolytic caps C4 C5 (DONE)
4) Move ribbon cable socket slightly lower so it doesnt foul on the case screw boss (WONTFIX - just trim the screw boss on the case )
5) Move C43 lower to remove chance of shorting with display retention tabs or remove C43 altogether (SOLUTION : Do Not Fit C43)

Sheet: FULLBOM
Number of Units Produced : | 1
Designator | Description | Quantity per Unit | Total Quantity | Supplier | Supplier Part Number | Alternate Part | Notes
R7,R8 | RES 2.2K | 2 | 2 | Mouser | 660-MF1/4DCT52R2201F |  | New part for v1.3R, was not on v1.2 boards
R55 | RES 47R | 1 | 1 | Mouser | 660-MF1/4DC47R0F
R53,R54,R59,R60 | RES 390R | 4 | 4 | Mouser | 660-MF1/4DCT52R3900F
C10,C11,C12,C13,C14,C17,C18,C19,C2,C21,C26,C28,C29,C3,C32,C37,C38,C39,C40,C41,C42,C44,C9 | CAP 0.1uF (0.1" spacing) 50V | 23 | 23 | Mouser | 80-C320C104K5R
R30 | RES 0.5R 1/2W | 1 | 1 | Mouser | 660-CF1/2CT52RR50J (https://www.mouser.com/Search/ProductDetail.aspx)
R2 | RES 1.2K | 1 | 1 | Mouser | 660-MF1/4DCT52R1201F
R18,R56,R57 | RES 1.5K | 3 | 3 | Mouser | 660-MF1/4DCT52R1501F
C4,C5 | 1000uF 16V minimum | 2 | 2 | Mouser | 647-UPW1E102MPD6
R10,R20,R21,R27,R28,R29,R3,R31,R32,R33,R34,R36,R37,R40,R42,R43,R44,R45,R47,R48,R51,R61 | RES 100K | 22 | 22 | Mouser | 660-MF1/4DC1003F
R38,R39,R41,R49,R5,R50,R52,R58 | RES 10K | 8 | 8 | Mouser | 660-MF1/4DCT52R1002F | 660-MF1/4DC1002F
C8 | CAP 10uF | 1 | 1 | Mouser | 647-USV1H100MFD1TP
C1 | CAP 10uF CER | 1 | 1 | Mouser | 810-FG11X7R1H106KRT6 |  | This was changed to a ceramic cap in case of reverse voltage dc supply
R1A | RES 12K | 1 | 1 | Mouser | 660-MF1/4DCT52R1202F
C15,C16 | CAP 18pF | 2 | 2 | Mouser | 80-C315C180J1G
F1 | 1A POLYFUSE | 1 | 1 | Mouser | 650-LVR100S
R14,R15,R19,R62 | RES 1K | 4 | 4 | Mouser | 660-MF1/4DCT52R1001F
R12,R23,R25,R26 | RES 1M | 4 | 4 | Mouser | 660-MF1/4DCT52R1004F
D1,D4 | DIODE 1N4004 | 2 | 2 | Mouser | 621-1N4004
D2,D3 | DIODE 1N4148 | 2 | 2 | Mouser | 512-1N4148
C25,C27 | CAP 1nF (0.1" spacing) | 2 | 2 | Mouser | 80-C315C102K1G
C20,C22,C23,C24,C30,C31,C33,C34,C35,C36,C43 | CAP 1uF (0.1" spacing) | 11 | 11 | Mouser | 80-C315C105K3R
R35,R46 | RES 200K | 2 | 2 | Mouser | 660-MF1/4DCT52R2003F
R11,R16,R17,R22,R24,R4 | RES 20K | 6 | 6 | Mouser | 660-MF1/4DCT52R2002F
J10,J11 | PAK100/2500-24 - 2425- 3M WALL HEADER | 2 | 2 | Mouser | 517-N2524-6002RB
Q7,Q8 | TRANS. 2N3904 | 2 | 2 | Mouser | 512-2N3904BU
R6 | RES 3.3K | 1 | 1 | Mouser | 660-MF1/4DCT52R3301F
R9,R13 | RES 4.7K | 2 | 2 | Mouser | 660-MF1/4DCT52R4701F
U3 | CD4066N | 1 | 1 | Mouser | 595-CD4066BE
TR1,TR2 | 42TL004 | 2 | 2 | Mouser | 42TL004-RC |  | Mouser has had problems keeping this transformer in stock. For those in North America, it's stocked at ABRA - https://abra-electronics.com/power-supplies-transformers-adapters/audio-transformers/miniature-audio-transformers-75mw-max-output/42tl004-miniature-audio-tran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
C6,C7 | CAP 470uF 16V | 2 | 2 | Mouser | 647-UHE1E471MPD
U13 | VREG 7805T | 1 | 1 | Mouser | 511-L7805ACP | 511-L7805CV
U11,U12 | VREG 7809TV | 2 | 2 | Mouser | 511-L7809CV (https://www.mouser.com/Search/ProductDetail.aspx?R=L7809CVvirtualkey51120000virtualkey511-L7809CV)
XTAL1 | 8MHZ XTAL HC-49S | 1 | 1 | Mouser | 717-9B-8.000MEEJ-B
U1 | ATMEGA 16P | 1 | 1 | Mouser | 556-ATMEGA16A-PU (https://www.mouser.com/Search/ProductDetail.aspx) | http://www.digikey.com/short/3fb4z5
LCD1 | LCD HD44780LCD-1602 | 1 | 1 | Mouser | 763-0216K1Z-NSW-BBW | 763-0216K1Z-NSW-FBW
Q3,Q6 | MOSFET IRF9Z24 | 2 | 2 | Mouser | 942-IRF9Z24NPBF (https://www.mouser.com/Search/ProductDetail.aspx)
Q1,Q2,Q4,Q5 | MOSFET IRL520N | 4 | 4 | Mouser | 942-IRL520NPBF (https://www.mouser.com/Search/ProductDetail.aspx)
JP1 | ISP 6 PIN | 1 | 1 | Mouser | 571-5-146254-3
U14 | LM2941 | 1 | 1 | Mouser | 926-LM2941CT/NOPB | 926-LM2941T/NOPB
U2 | LM324N | 1 | 1 | Mouser | 595-LM324N | 595-LM324NE3
U10,U4 | LM358N | 2 | 2 | Mouser | 512-LM358N | 926-LM358N/NOPB
U8A (OPTIONAL - USE U8B INSTEAD) | MAX548 | 0 | 0 | Mouser | 700-MAX548ACPA |  | U8A is only for V1.5 and below firmware.We suggest using U8B LTC1661 purchased from Digikey (see below) and firmware 1.6 and above
U8B | LTC1661 (For V1.6 and above firmware) | 1 | 1 | Mouser | LTC1661CN8#PBF-ND |  | This is the suggested DAC (Now sold at Mouser: https://www.mouser.com/ProductDetail/Analog-Devices/LTC1661CN8PBF)
LED1,LED2,LED3,LED4 | 5MM LED | 4 | 4 | Mouser | 606-4304H1
U9 | MAX232 | 1 | 1 | Mouser | 700-MAX232CPE
SOCKET FOR U2,U3 | DIL 14 IC SOCKET | 2 | 2 | Mouser | 517-4814-3004-CP
SOCKET FOR U9 | DIL 16 IC SOCKET | 1 | 1 | Mouser | 517-4816-3004-CP
SOCKET FOR U1 | DIL 40 IC SOCKET | 1 | 1 | Mouser | 575-11041640410010
SOCKET FOR U10,U4,U8(A/B) | DIL 8 IC SOCKET | 4 | 4 | Mouser | 571-1-2199298-2
JP6,JP7 | 2x1 SIP HEADER 0.1" | 2 | 2 | Mouser | 571-5-146285-2
JUMPER | 0.1" JUMPER | 3 | 3 | Mouser | 571-382811-6
VR1, VR2 | ALPS 9mm 10K Pot | 2 | 2 | Mouser | 688-RK09L1140A2U (https://www.mouser.com/Search/ProductDetail.aspx)
VR3 | ALPS 9mm 10K Dual Gang Pot | 1 | 1 | Mouser | 688-RK09L1240A12 (https://www.mouser.com/Search/ProductDetail.aspx)
VR4 | Bourns 3362P 10K Pot | 1 | 1 | Mouser | 3362P-1-103LF (http://www.mouser.com/ProductDetail/Bourns/3362P-1-103LF/)
S1,S2,S3,S4 | Buttons | 4 | 4 | Mouser | 611-D6C90F2LFS
J2,J3,J4,J5,J6,J7 | 3.5mm stereo jack | 6 | 6 | Mouser | 806-STX-3100-5NB (https://www.mouser.com/Search/ProductDetail.aspx)
J8 | 2.1/5.5mm DC jack | 1 | 1 | Mouser | 490-PJ-002A (https://www.mouser.com/Search/ProductDetail.aspx?R=PJ-002Avirtualkey51780000virtualkey490-PJ-002A)
S5 | Toggle Switch with safety actuator | 1 | 1 | Mouser | 611-7101K2AV2BE (https://www.mouser.com/Search/ProductDetail.aspx) | 611-7101K2AV2QE
J9 | Radio Header | 1 | 1 | Mouser | 538-90147-1206
PACTEC Case | Case | 1 | 1 | Mouser | 616-63025-510-000 (https://www.mouser.com/Search/ProductDetail.aspx) | Suggest buying directly from PACTEC or sourcing a compatible case elsewhere http://bit.ly/2iuAHbB . UK SOURCE : http://uk.rs-online.com/web/p/consoles-desktop-enclosures/1047312/
Gray button covers | Button Cover | 2 | 2 | Mouser | 611-BTND610F (https://www.mouser.com/Search/ProductDetail.aspx?R=BTND610Fvirtualkey61170000virtualkey611-BTND610F) | 611-BTND690F
White button covers | Button Cover | 2 | 2 | Mouser | 611-BTND600F (https://www.mouser.com/Search/ProductDetail.aspx)
LCD HEADER | LCD Header | 1 | 1 | Mouser | 710-61301611121
KNOB | Potentiometer KNOB | 3 | 3 | Mouser | 450-BA761
BAT1 (Recommended Option) | Lead Acid Battery 2.5AH | 1 | 1 | Mouser | 547-PS-1220 | UK SOURCE http://uk.rs-online.com/web/p/lead-acid-rechargeable-batteries/5375444/
BAT1 (Option) | Lead Acid Battery 1.4AH | 0 | 0 | Mouser | 547-PS-1212
BAT 1 LUGS | Lugs For Connecting to BAT1 | 2 | 2 | Mouser | 534-8291 |  | Crimp on Lugs for Battery
Power Supply 15V (Recommended Option) | 15V, > 1A , 5.5MM OD Plug | 1 | 1 | Mouser | 709-GE24I15-P1J
Power Supply AC Plug | Set of Universal AC Plugs for power supply | 1 | 1 | Mouser | 709-ACPLUG-MIX
Power Supply 18 V (Not recommended - may cause overvoltage error on boot up) | 18V, 1A , 5.5MM OD Plug | 0 | 0 | Mouser | 709-GST18U18-P1J |  | Use 18V version to give linear regulator a bit more headroom . 15V will work fine though
IDC connectors for ribbon cable | Ribbon Cable Connector(or buy a ready made cable) | 2 | 2 | Mouser | 517-8924 (https://www.mouser.com/Search/ProductDetail.aspx?R=89124-0103virtualkey51750000virtualkey517-8924) |  | Suggest sourcing a ready made cable . See misc hardware below
24 conductor ribbon cable | Bare Ribbon Cable (or buy a ready made cable) | 1 | 1 | Mouser | 517-3365/24-100 |  | See above.
Radio | HC-05 Bluetooth Module | 1 | 1 | Amazon | HC-05 (multiple amazon vendors) |  | http://amzn.to/2iiOXz6
J1 T Connector (Deans Connector)- DNF (Unless you want to , then F away) | 12V Battery Connector | 1 | 1 | Hobbyking | SKU: 015000231-0 |  | http://bit.ly/2jpP4gQ
MISC HARDWARE
Ribbon Cable 24 pin, 2.54mm pitch IDC. | Ribbon Cable | 1 | 1 | Amazon | B01BGNLPX0 |  | http://amzn.to/2jp34ay
#4 x 1/4" sheet metal screw (Main board to case) | Screw | 2 | 2 | McMaster-Carr | 90190A106 |  | http://bit.ly/2jCJuVR
M2.5 x 20mm socket head screw (Front panel screws) | Screw | 6 | 6 | McMaster-Carr | 91290A108 |  | http://bit.ly/2jhEohH
M2.5 nut (Front panel nut) | Screw | 22 | 22 | McMaster-Carr | 90591A270 |  | http://bit.ly/2jpf0Jq
18 Gauge Wire : | Battery Leads (quantity ft) | 5 | 5 | McMaster-Carr | 8054T15 |  | http://bit.ly/2jCHwER
Heat Shrink | Heat Shrink Tubing | 1 | 1 | McMaster-Carr | 7496K43 |  | http://bit.ly/2jYteSl

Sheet: MOUSERBOM1
Designator | Description | Quantity per Unit | Supplier | Supplier Part Number | Mfg Part Number | Alternate Part
R7,R8 | RES 2.2K | 2 | Mouser | 660-MF1/4DCT52R2201F | MF1/4DCT52R2201F
R55 | RES 47R | 1 | Mouser | 660-MF1/4DC47R0F | MF1/4DC47R0F
R53,R54,R59,R60 | RES 390R | 4 | Mouser | 660-MF1/4DCT52R3900F | MF1/4DCT52R3900F
C10,C11,C12,C13,C14,C17,C18,C19,C2,C21,C26,C28,C29,C3,C32,C37,C38,C39,C40,C41,C42,C44,C9 | CAP 0.1uF (0.1" spacing) 50V | 23 | Mouser | 80-C320C104K5R | C320C104K5R5TA
R30 | RES 0.5R 1/2W | 1 | Mouser | 660-CF1/2CT52RR50J | CF1/2CT52RR50J
R2 | RES 1.2K | 1 | Mouser | 660-MF1/4DCT52R1201F | MF1/4DCT52R1201F
R18,R56,R57 | RES 1.5K | 3 | Mouser | 660-MF1/4DCT52R1501F | MF1/4DCT52R1501F
C4,C5 | 1000uF 16V minimum | 2 | Mouser | 647-UPW1E102MPD6 | UPW1E102MPD6
R10,R20,R21,R27,R28,R29,R3,R31,R32,R33,R34,R36,R37,R40,R42,R43,R44,R45,R47,R48,R51,R61 | RES 100K | 22 | Mouser | 660-MF1/4DC1003F | MF1/4DC1003F
R38,R39,R41,R49,R5,R50,R52,R58 | RES 10K | 8 | Mouser | 660-MF1/4DC1002F | MF1/4DC1002F | 660-MF1/4DCT52R1002F
C8 | CAP 10uF | 1 | Mouser | 647-USV1H100MFD1TP | USV1H100MFD1TP
C1 | CAP 10uF CER | 1 | Mouser | 810-FG11X7R1H106KRT6 | FG11X7R1H106KRT06
R1A | RES 12K | 1 | Mouser | 660-MF1/4DCT52R1202F | MF1/4DCT52R1202F
C15,C16 | CAP 18pF | 2 | Mouser | 80-C315C180J1G | C315C180J1G5TA
F1 | 1A POLYFUSE | 1 | Mouser | 650-LVR100S | LVR100S
R14,R15,R19,R62 | RES 1K | 4 | Mouser | 660-MF1/4DCT52R1001F | MF1/4DCT52R1001F
R12,R23,R25,R26 | RES 1M | 4 | Mouser | 660-MF1/4DCT52R1004F | MF1/4DCT52R1004F
D1,D4 | DIODE 1N4004 | 2 | Mouser | 621-1N4004 | 1N4004-T
D2,D3 | DIODE 1N4148 | 2 | Mouser | 512-1N4148 | 1N4148
C25,C27 | CAP 1nF (0.1" spacing) | 2 | Mouser | 80-C315C102K1G | C315C102K1G5TA
C20,C22,C23,C24,C30,C31,C33,C34,C35,C36,C43 | CAP 1uF (0.1" spacing) | 11 | Mouser | 80-C315C105K3R | C315C105K3R5TA
R35,R46 | RES 200K | 2 | Mouser | 660-MF1/4DCT52R2003F | MF1/4DCT52R2003F
R11,R16,R17,R22,R24,R4 | RES 20K | 6 | Mouser | 660-MF1/4DCT52R2002F | MF1/4DCT52R2002F
J10,J11 | PAK100/2500-24 - 2425- 3M WALL HEADER | 2 | Mouser | 517-N2524-6002RB | N2524-6002RB
Q7,Q8 | TRANS. 2N3904 | 2 | Mouser | 512-2N3904BU | 2N3904BU
R6 | RES 3.3K | 1 | Mouser | 660-MF1/4DCT52R3301F | MF1/4DCT52R3301F
R9,R13 | RES 4.7K | 2 | Mouser | 660-MF1/4DCT52R4701F | MF1/4DCT52R4701F
U3 | CD4066N | 1 | Mouser | 595-CD4066BE | CD4066BE
TR1,TR2 | 42TL004 | 2 | Mouser | 42TL004-RC | 42TL004-RC
C6,C7 | CAP 470uF 16V | 2 | Mouser | 647-UHE1E471MPD | UHE1E471MPD
U13 | VREG 7805T | 1 | Mouser | 511-L7805ACP | L7805ACP | 511-L7805CV or 580-OKI78SR5/1.5W36C (drop in switcher replacement)
U11,U12 | VREG 7809TV | 2 | Mouser | 511-L7809CV | L7809CV
XTAL1 | 8MHZ XTAL HC-49S | 1 | Mouser | 717-9B-8.000MEEJ-B | 9B-8.000MEEJ-B
U1 | ATMEGA 16P | 1 | Mouser | 556-ATMEGA16A-PU | ATMEGA16A-PU | 556-ATMEGA16L-8PU ELSE SEE DIGIKEY ON NONMOUSER
LCD1 | LCD HD44780LCD-1602 | 1 | Mouser | 763-0216K1Z-NSW-BBW | NHD-0216K1Z-NSW-BBW-L | 763-0216K1Z-NSW-FBW
Q3,Q6 | MOSFET IRF9Z24 | 2 | Mouser | 942-IRF9Z24NPBF | IRF9Z24NPBF
Q1,Q2,Q4,Q5 | MOSFET IRL520N | 4 | Mouser | 942-IRL520NPBF | IRL520NPBF
JP1 | ISP 6 PIN | 1 | Mouser | 571-5-146254-3 | 5-146254-3
U14 | LM2941 | 1 | Mouser | 926-LM2941CT/NOPB | LM2941CT/NOPB | 926-LM2941T/NOPB
U2 | LM324N | 1 | Mouser | 595-LM324NE3 | LM324NE3 | 595-LM324N
U10,U4 | LM358N | 2 | Mouser | 512-LM358N | LM358N | 926-LM358N/NOPB
U8B | LTC1661 | 1 | Mouser | 584-LTC1661CN8#PBF | LTC1661CN8#PBF
LED1,LED2,LED3,LED4 | 5MM LED | 4 | Mouser | 606-4304H1 | 4304H1
U9 | MAX232 | 1 | Mouser | 700-MAX232CPE | MAX232CPE
SOCKET FOR U2,U3 | DIL 14 IC SOCKET | 2 | Mouser | 517-4814-3004-CP | 4814-3004-CP
SOCKET FOR U9 | DIL 16 IC SOCKET | 1 | Mouser | 517-4816-3004-CP | 4816-3004-CP
SOCKET FOR U1 | DIL 40 IC SOCKET | 1 | Mouser | 575-11041640410010 | 110-41-640-41-001000
SOCKET FOR U10,U4,U8(A/B) | DIL 8 IC SOCKET | 4 | Mouser | 571-1-2199298-2 | 1-2199298-2
JP6,JP7 | 2x1 SIP HEADER 0.1 | 2 | Mouser | 571-5-146285-2 | 5-146285-2
VR1, VR2 | ALPS 9mm 10K Pot | 2 | Mouser | 688-RK09L1140A2U | RK09L1140A2U
VR3 | ALPS 9mm 10K Dual Gang Pot | 1 | Mouser | 688-RK09L1240A12 | RK09L1240A12
VR4 | Bourns 3362P 10K Pot | 1 | Mouser | 3362P-1-103LF | 3362P-1-103LF
S1,S2,S3,S4 | Buttons | 4 | Mouser | 611-D6C90F2LFS | D6C90 F2 LFS
J2,J3,J4,J5,J6,J7 | 3.5mm stereo jack | 6 | Mouser | 806-STX-3100-5NB | STX-3100-5NB
J8 | 2.1/5.5mm DC jack | 1 | Mouser | 490-PJ-002A | PJ-002A
S5 | Toggle Switch with safety actuator | 1 | Mouser | 611-7101K2AV2BE | 7101K2AV2BE | 611-7101K2AV2QE
J9 | Radio Header | 1 | Mouser | 538-90147-1206 | 90147-1206
Gray button covers | Button Cover | 2 | Mouser | 611-BTND610F | BTND610F | 611-BTND690F
White button covers | Button Cover | 2 | Mouser | 611-BTND600F | BTN D6 00 F
LCD HEADER | LCD Header | 1 | Mouser | 710-61301611121 | 61301611121
Knob | Potentiometer Knob | 3 | Mouser | 450-BA761 | BA761
BAT1 | Lead Acid Battery | 1 | Mouser | 547-PS-1220 | PS-1220
BAT1 Lugs | Crimp Lubs for BAT1 | 2 | Mouser | 534-8291 | 534-8291
Power Supply | 15V, 1.6A .5.5mm OD plug | 1 | Mouser | 709-GE24I15-P1J | GE24I15-P1J | 709-GST25U15-P1J
Power Supply AC Plug | Set of Universal AC Plugs for All Wall Sockets | 1 | Mouser | 709-ACPLUG-MIX | AC Plug-MIX

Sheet: NONMOUSER
Parts Not Sourced from Mouser
Part | Quantity
Bluetooth Radio HC - 05 | 1
Amazon : http://amzn.to/2l0UEoj
3M VHB double sided tape
Amazon : http://amzn.to/2nTkawE
LM324N (Digikey if mouser is out of stock)
Digikey : http://www.digikey.com/short/3fb4md | 1
ATMEGA 16 (Digikey if mouser is out of stock)
Digikey : http://www.digikey.com/short/3fb4z5 | 1
Ribbon Cable 24 pin, 2.54mm pitch IDC. | 1
Digikey : https://tinyurl.com/yap52fll
Amazon : http://amzn.to/2jp34ay
18 Gauge Wire : | 5ft
McMaster-Carr: http://bit.ly/2jCHwER
Heat Shrink Tubing: | 1 pack
McMaster-Carr : http://bit.ly/2jYteSl
#4 x 1/4" sheet metal screw (Main board to case) | 2
McMaster-Carr : http://bit.ly/2jCJuVR
M2.5 x 20mm socket head screw (Front panel screws) | 6
McMaster-Carr : http://bit.ly/2jhEohH
M2.5 nut (Front panel nut) | 22
McMaster-Carr : http://bit.ly/2jpf0Jq
T Connector (Deans Connector - OPTIONAL) | 1
Hobbyking : http://bit.ly/2jpP4gQ
Lead Acid Battery
Digikey : https://www.digikey.com/short/3ff7t4
Pactec Case | 1
Allied : http://www.alliedelec.com/pactec-cm86-225-000-k/70080019/
Pactec : https://www.pactecenclosures.com/product-detail.php?productid=72&classid=26&seriesid=45
UK Souce RS Online : http://uk.rs-online.com/web/p/consoles-desktop-enclosures/1047312/
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

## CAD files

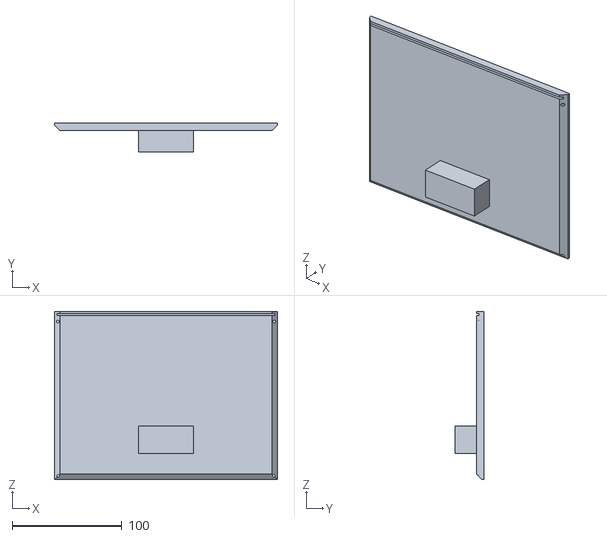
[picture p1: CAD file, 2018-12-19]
case/lid_v1.26.stl
203.0 x 26.5 x 153.0

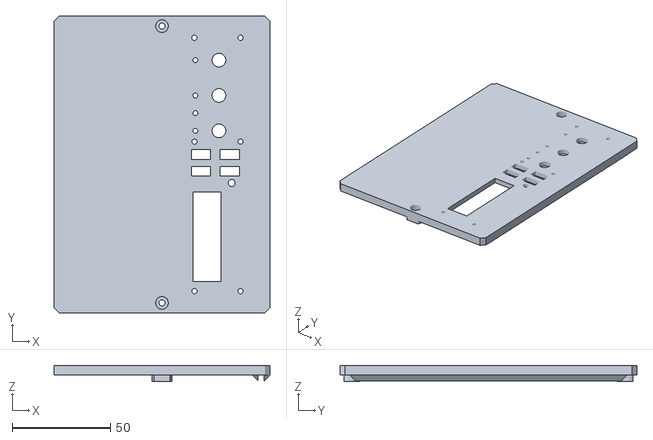
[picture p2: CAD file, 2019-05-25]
kicad_smd_files/case/Lid.stl
110.0 x 151.0 x 8.40

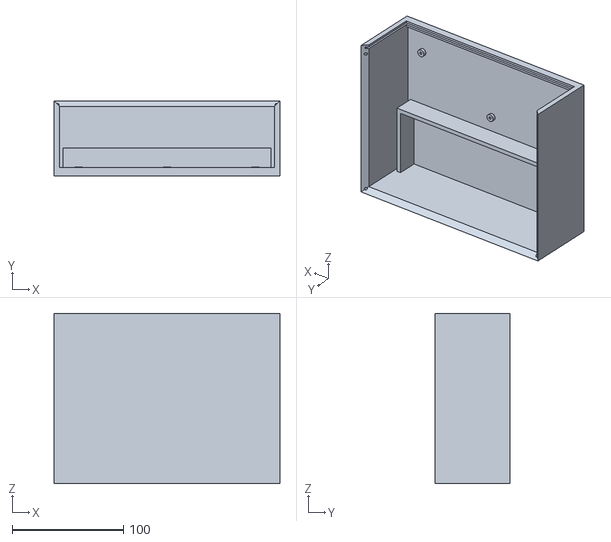
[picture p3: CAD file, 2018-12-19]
case/case_v1.26.stl
203.0 x 67.5 x 153.0

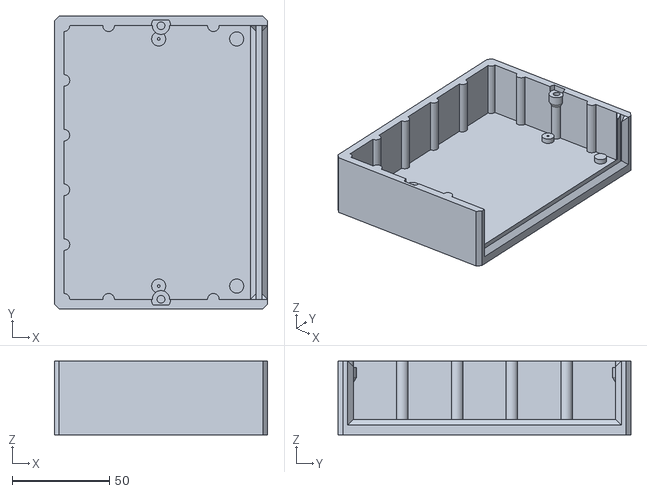
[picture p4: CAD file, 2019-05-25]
kicad_smd_files/case/Box.stl
110.0 x 151.0 x 38.0

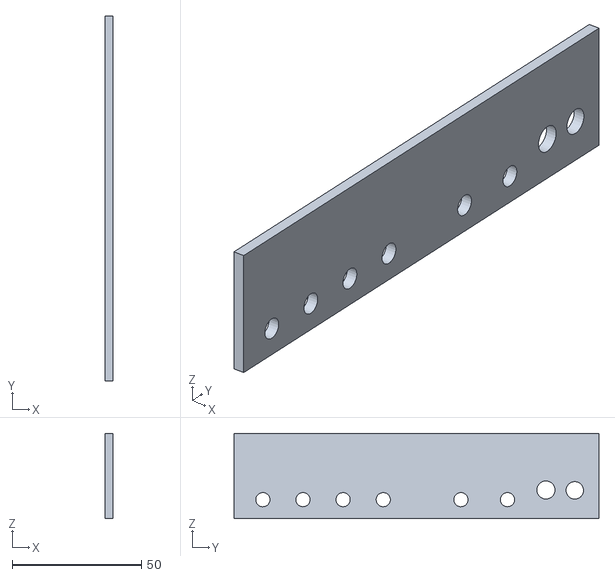
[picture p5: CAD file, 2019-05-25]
kicad_smd_files/case/Front_Faceplate.stl
3.00 x 141.0 x 33.0

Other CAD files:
case/case_v1.26.f3d
kicad_smd_files/case/mk312b-smd v14.f3d

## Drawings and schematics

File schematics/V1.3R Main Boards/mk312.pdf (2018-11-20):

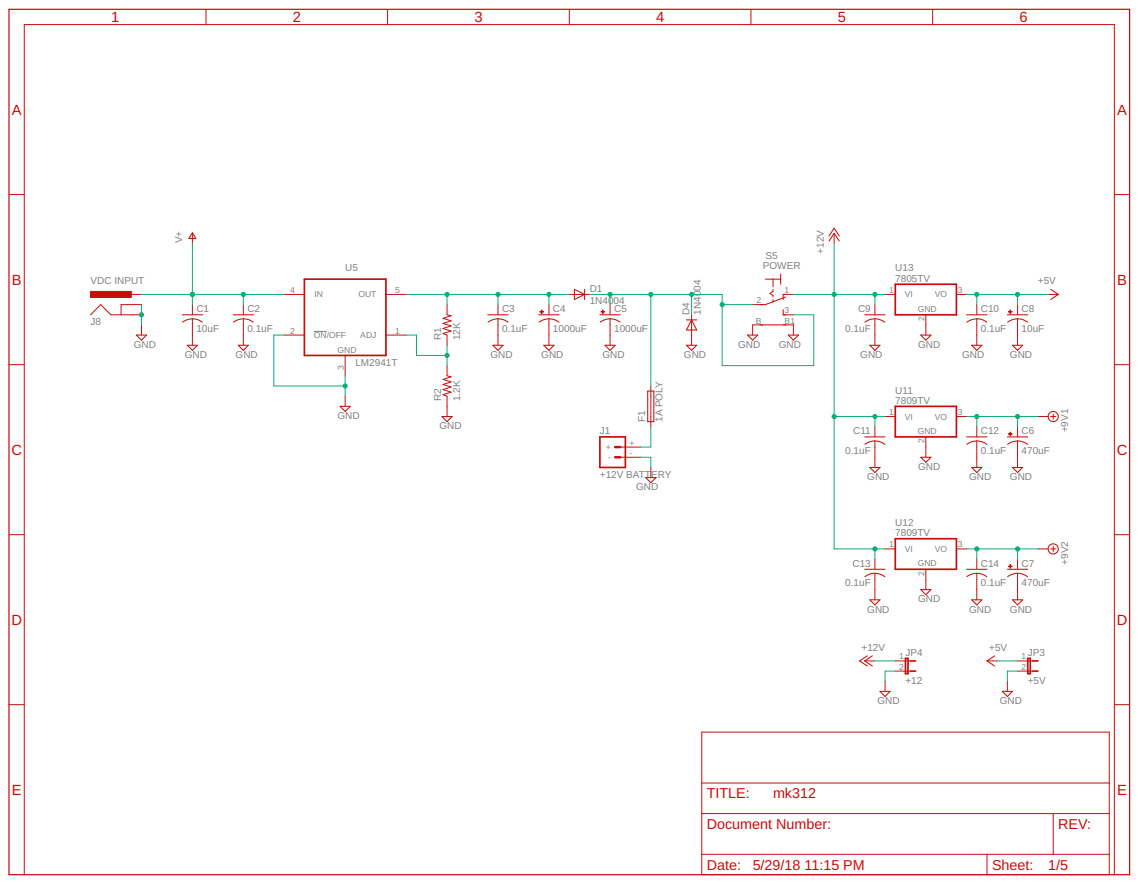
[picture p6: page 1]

Document Number: | REV:

Date: 5/29/18 11:15 PM | Sheet: 1/5

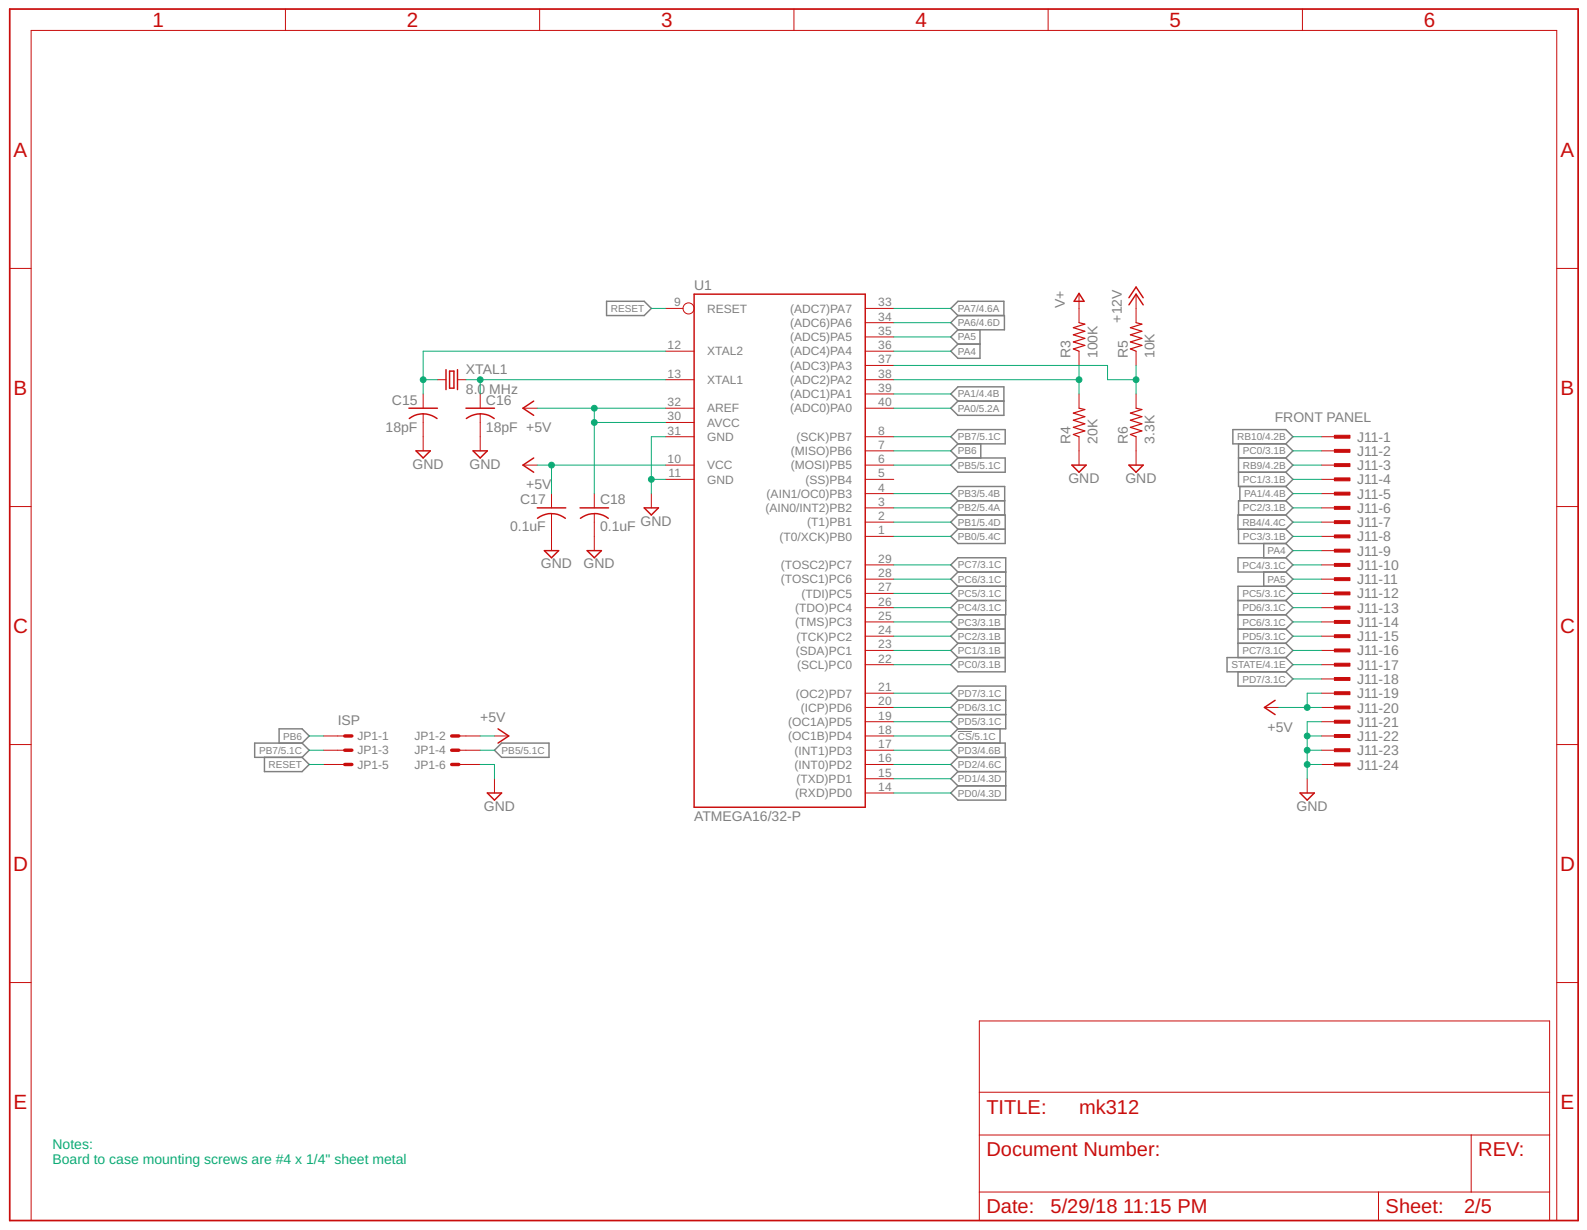
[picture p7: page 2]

Notes: Board to case mounting screws are #4 x 1/4" sheet metal

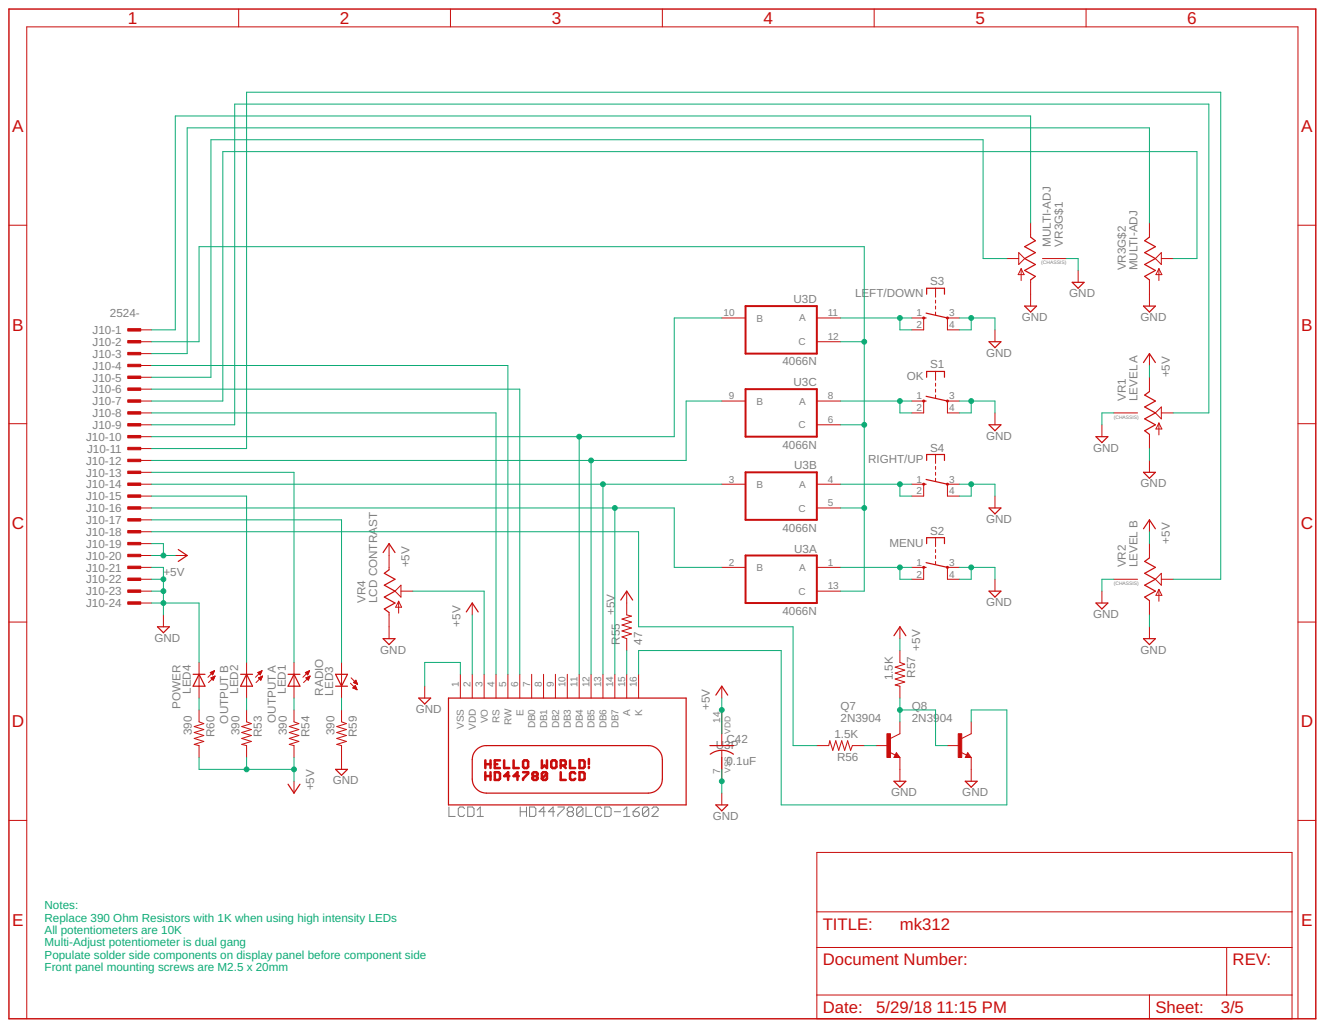
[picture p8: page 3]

MULTI-ADJ MULTI-ADJ LEVEL A LEVEL B

Notes: Replace 390 Ohm Resistors with 1K when using high intensity LEDs All potentiometers are 10K Multi-Adjust potentiometer is dual gang Populate solder side components on display panel before component side Front panel mounting screws are M2.5 x 20mm

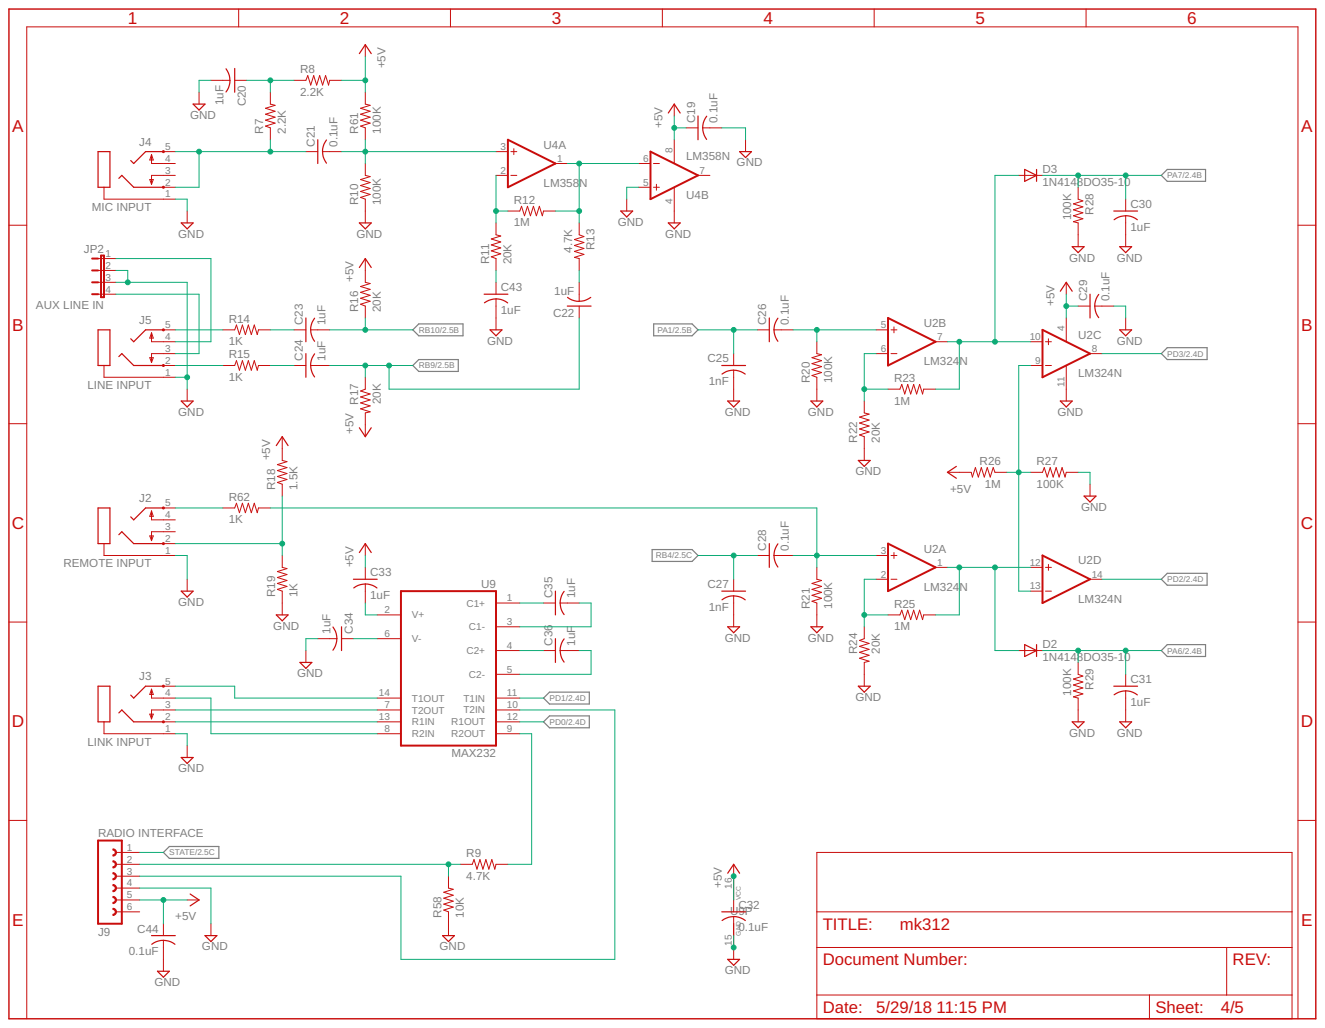
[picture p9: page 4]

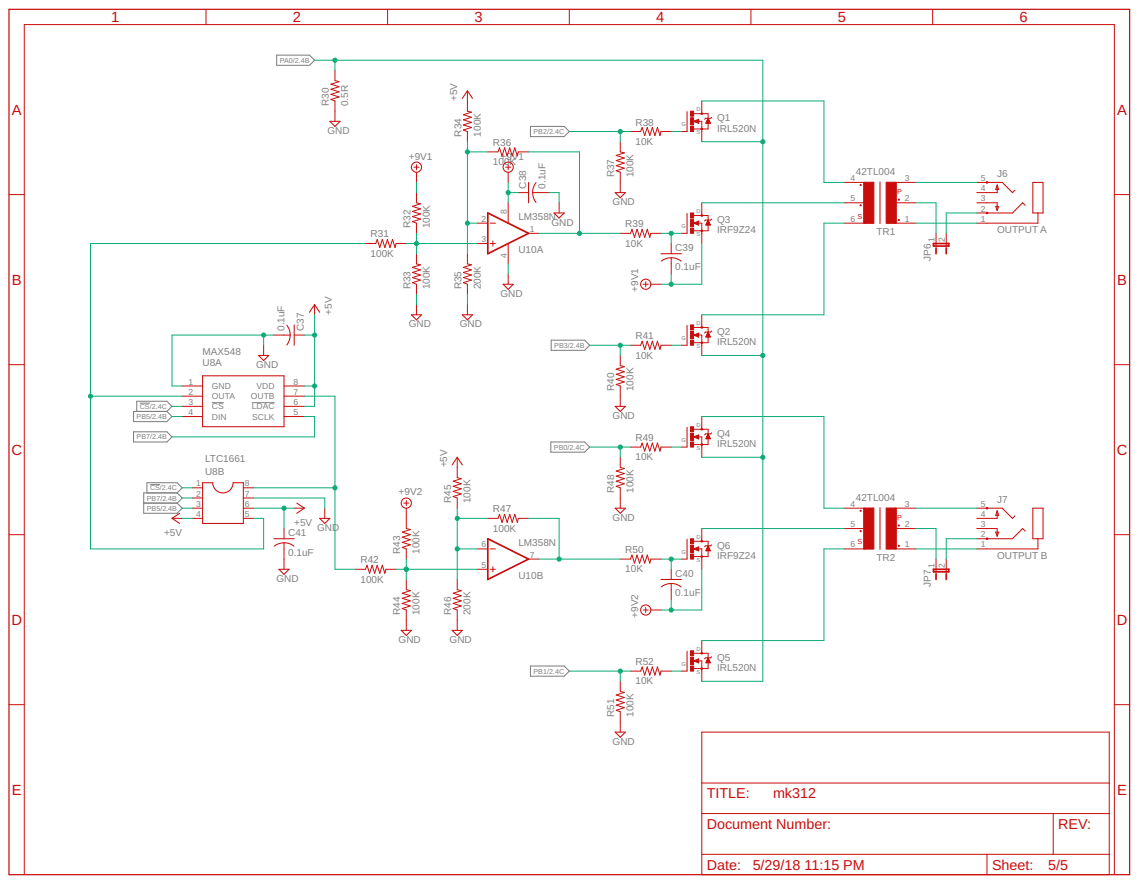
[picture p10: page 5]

100K 10K GND10K 100K GND IRL520N IRL520N 10K IRF9Z24 0.1uF GND 100K 100K 100K 100K 200K GND GND 100K +5V 100K 10K GND10K IRL520N IRL520N 10K IRF9Z24 0.1uF 100K 100K 100K 200K GND GND +5V 100K 100K +5V MAX548 OUTPUT A OUTPUT B 0.5R GND 100K GND LM358N LM358N 42TL004 42TL004 +9V1 +9V1 +9V2 +9V2 +9V1 0.1uF 0.1uF GND GND LTC1661 +5V +5V GND 0.1uF GND R37 R38 R41 R40 DS G Q1 DS G Q2 R39 DS G Q3 C39 R36 R33 R32 R34 R35 R31 R48 R49 R52 DS G Q4 DS G Q5 R50 DS G Q6 C40 R44 R43 R45 R46 R51 R42 GND 1 OUTA 2 CS 3 DIN 4 SCLK 5 LDAC 6 OUTB 7 VDD 8 U8A 54321 J6 54321 J7 R30 R47 23 1 U10A 65 7 U10B 8 4 12 456 3 TR1 12 456 3 TR2 12 JP6 12 JP7 C37 C38 1234 5678 U8B C41 PB3/2.4B PB1/2.4C PB7/2.4B PB7/2.4B CS/2.4C CS/2.4C PA0/2.4B PB5/2.4B PB5/2.4B PB2/2.4CPB0/2.4C S P S P ABCDE ABCDE 1 2 3 4 5 6 Date: Sheet: REV: TITLE: Document Number: 5/29/18 11:15 PM 5/5 mk312

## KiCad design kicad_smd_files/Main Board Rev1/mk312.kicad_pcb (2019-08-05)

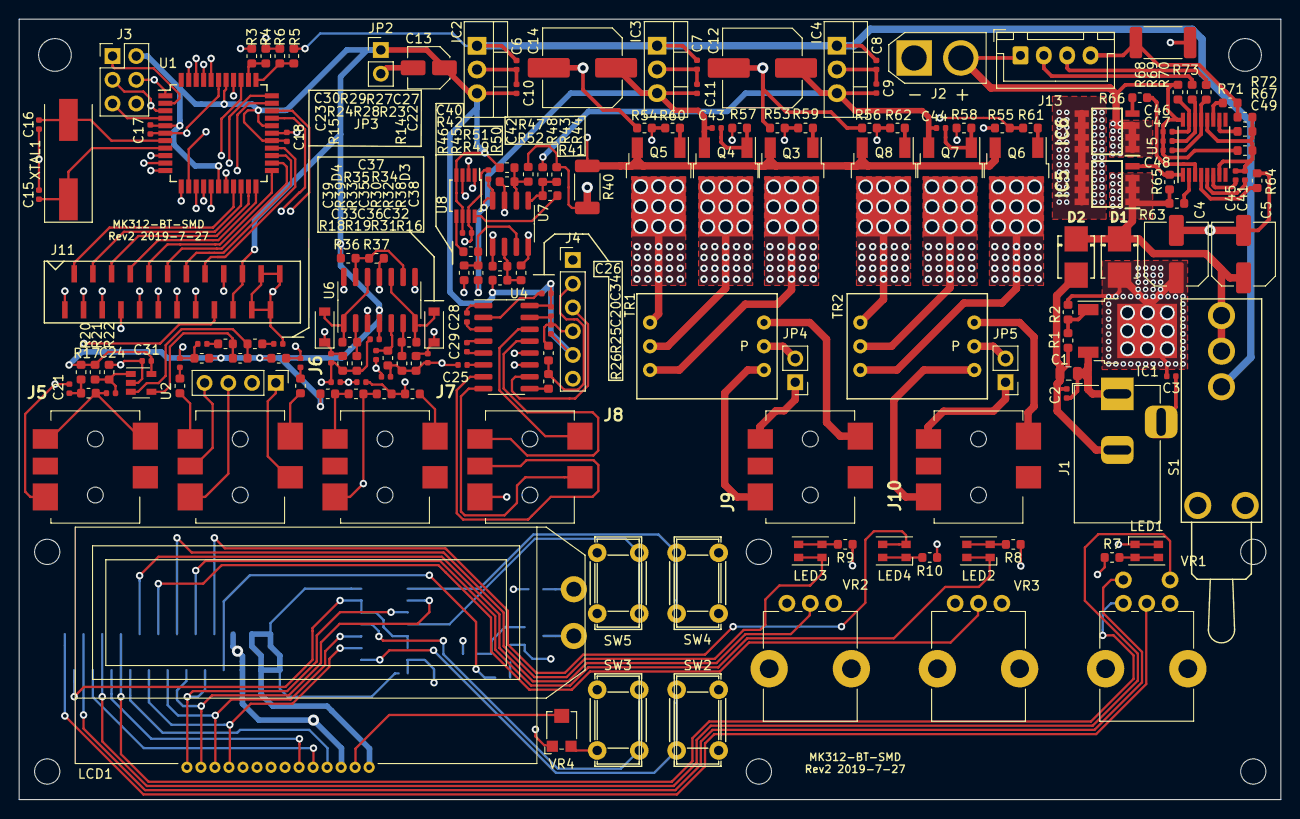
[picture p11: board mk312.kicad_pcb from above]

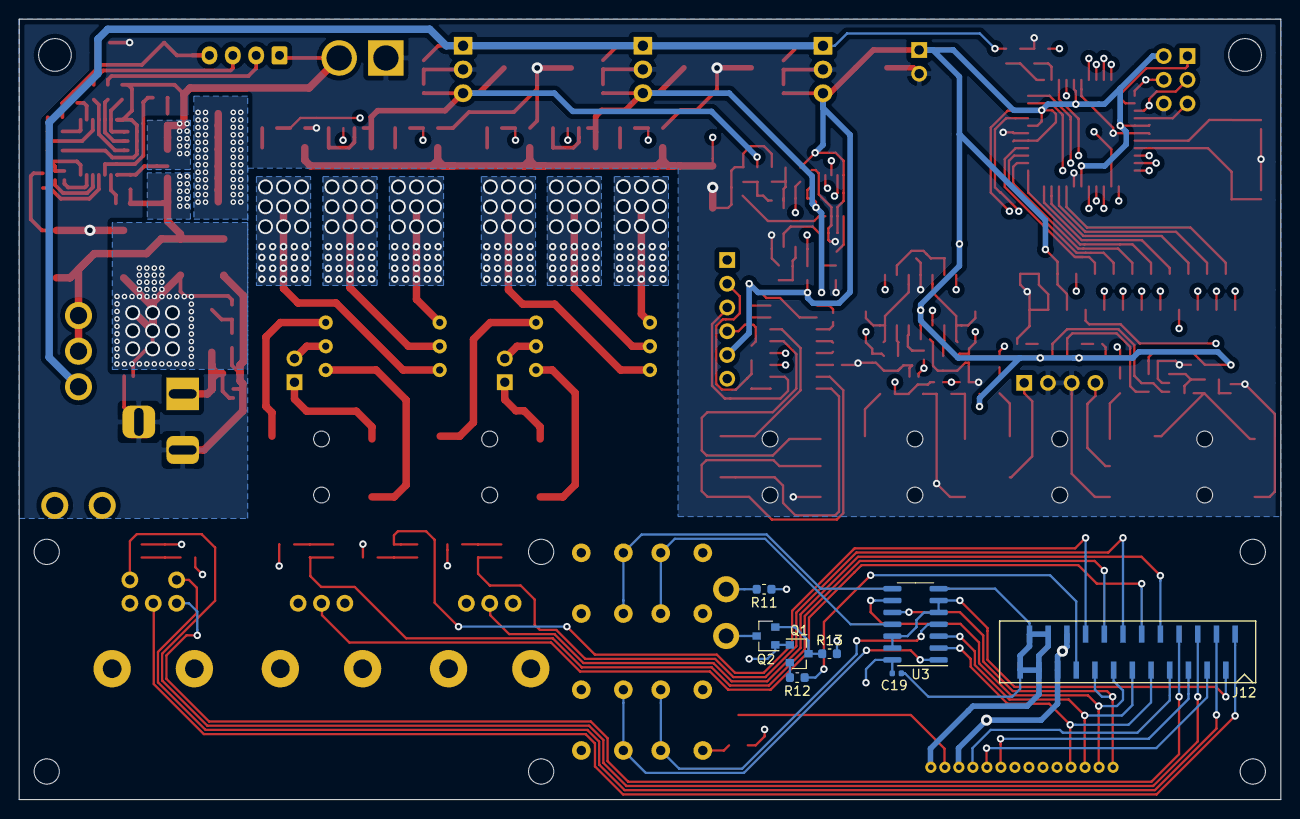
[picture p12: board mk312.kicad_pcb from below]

Board: 4 copper layers, 135.0 x 83.5 mm, 190 parts (8 on the bottom side), 161 nets.

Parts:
C1: 10uF; C_0805_2012Metric
C2, C3, C6, C7, C8, C9, C10, C11, C17, C18, C19, C20, C24, C31, C34, C35, C36, C37, C40, C41, C42, C43, C44, C45, C46, C47, C48: 0.1uF; C_0402_1005Metric
C4, C5: 100uF; C_Elec_6.3x7.7
C12, C14: 470uF; C_Elec_8x10.2
C13: 10uF; C_Elec_4x5.8
C15, C16: 18pF; C_0402_1005Metric
C21, C22, C23, C25, C26, C27, C28, C29, C30, C38, C39: 1uF; C_0402_1005Metric
C32, C33: 1nF; C_0402_1005Metric
C49: 2.2uF; C_0603_1608Metric
D1, D2: GF1G-E3/67A; DO-214BA
D3, D4: 1N4148W-E3-08; D_SOD-123
H1, H2, H3, H4, H5, H6: MountingHole; MountingHole_2.7mm_M2.5
H7, H8: MountingHole; MountingHole_3.5mm
IC1: LMS8117ADTX-ADJ; TO-252-2
IC2: L7805CV; TO-220-3_Vertical
IC3, IC4: L7809ABV; TO-220-3_Vertical
IC5, IC6: SI4435FDY-T1-GE3; SOIC127P600X175-8N
J1: Barrel_Jack_MountingPin; BarrelJack_Horizontal
J2: +12V Battery; AMASS_XT30U-M_1x02_P5.0mm_Vertical
J3: Conn_02x03_Odd_Even; PinHeader_2x03_P2.54mm_Vertical
J4: RADIO INTERFACE; PinHeader_1x06_P2.54mm_Vertical
J5: MIC INPUT; SJ13515SMTTR
J6: LINE INPUT; SJ13515SMTTR
J7: REMOTE INPUT; SJ13515SMTTR
J8: LINK INPUT; SJ13515SMTTR
J9: OUTPUT A; SJ13515SMTTR
J10: OUTPUT B; SJ13515SMTTR
J11, J12: Conn_01x24_Male; HFW24S-2STE1LF
J13: Conn_01x04; JST_XH_B4B-XH-A_1x04_P2.50mm_Vertical
JP2: +5V; PinHeader_1x02_P2.54mm_Vertical
JP3: AUX LINE IN; PinHeader_1x04_P2.54mm_Vertical
JP4: A RING; PinHeader_1x02_P2.54mm_Vertical
JP5: B RING; PinHeader_1x02_P2.54mm_Vertical
LCD1: NHD-C0216AZ-FSW-GBW
LED1: POWER; LED_Cree-PLCC4_3.2x2.8mm_CCW
LED2: OUTPUT B; LED_Cree-PLCC4_3.2x2.8mm_CCW
LED3: OUTPUT A; LED_Cree-PLCC4_3.2x2.8mm_CCW
LED4: STATE; LED_Cree-PLCC4_3.2x2.8mm_CCW
Q1, Q2: MMBT3904-7-F; SOT-23
Q3, Q5, Q6, Q8: IRFR9024NTRPBF; TO-252-2
Q4, Q7: IRLR120NTRPBF; TO-252-2
R1, R14, R15, R16, R19, R64, R67, R68, R69, R70, R71: 1K; R_0603_1608Metric
R2: 110; R_0603_1608Metric
R3, R21, R22, R30, R31, R37, R38, R39, R41, R42, R43, R44, R45, R46, R47, R49, R51, R52, R53, R54, R55, R56: 100K; R_0603_1608Metric
R4, R23, R24, R27, R32, R33: 20K; R_0603_1608Metric
R5, R25, R57, R58, R59, R60, R61, R62: 10K; R_0603_1608Metric
R6: 3.3K; R_0603_1608Metric
R7, R8, R9, R10: 390; R_0603_1608Metric
R11: 130; R_0603_1608Metric
R12, R13, R18: 1.5K; R_0603_1608Metric
R17, R20: 2.2K; R_0603_1608Metric
R26, R29: 4.7K; R_0603_1608Metric
R28, R34, R35, R36, R65: 1M; R_0603_1608Metric
R40: 0.5R 1/2W; R_2010_5025Metric
R48, R50: 200K; R_0603_1608Metric
R63, R66: 5.1K; R_0603_1608Metric
R72: 51; R_0603_1608Metric
R73: 0.2R 2W; R_2512_6332Metric
S1: POWER; E-Switch_M7_SPDT
SW2: LEFT/DOWN; E-Switch_Tactile_TL1105
SW3: OK; E-Switch_Tactile_TL1105
SW4: RIGHT/UP; E-Switch_Tactile_TL1105
SW5: MENU; E-Switch_Tactile_TL1105
TR1, TR2: 42TL004; 42TL
U1: ATmega16-16AU; TQFP-44_10x10mm_P0.8mm
U2: MCP6L01U; SOT-23-5
U3: CD4066B; SOIC-14_3.9x8.7mm_P1.27mm
U4: SP232E; SOIC-16_3.9x9.9mm_P1.27mm
U5: S-8254A; TSSOP-16_4.4x5mm_P0.65mm
U6: LM324N; SOIC-14_3.9x8.7mm_P1.27mm
U7: LM358N; SOIC-8_3.9x4.9mm_P1.27mm
U8: LTC1661; MSOP-8_3x3mm_P0.65mm
VR1: MULTI-ADJ; Potentiometer_Alps_RK09K_Dual_Vertical
VR2: LEVEL A; Potentiometer_Alps_RK09K_Single_Vertical
VR3: LEVEL B; Potentiometer_Alps_RK09K_Single_Vertical
VR4: LCD CONTRAST; Potentiometer_Bourns_TC33X_Vertical
XTAL1: 8.0 MHz; Crystal_SMD_HC49-SD

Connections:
+5V: C10.1, C13.1, C17.1, C18.1, C20.1, C26.1, C31.2, C34.2, C37.2, C40.1, IC2.3, J3.2, J4.5, J11.19, J11.20, JP2.1, R18.2, R20.1, R21.1, R23.1, R24.2, R36.2, R47.1, R49.1, U1.5, U1.17, U1.27, U1.29, U1.38, U2.5, U4.16, U6.4, U8.4, U8.6
+5VD: C19.1, J12.19, J12.20, LCD1.3, R7.1, R8.1, R9.1, R11.1, R13.2, U3.14, VR2.3, VR3.3, VR4.1
+9V1: C11.1, C14.1, C42.1, C43.2, IC3.3, Q4.3, R45.1, U7.8
+9V2: C9.1, C12.1, C44.2, IC4.3, Q7.3, R43.1
+12V: C6.1, C7.1, C8.1, IC2.1, IC3.1, IC4.1, R5.2, S1.1
+VDC: C1.1, C2.1, IC1.3, J1.1, R3.1
GND: C1.2, C2.2, C3.2, C4.2, C5.2, C6.2, C7.2, C8.2, C9.2, C10.2, C11.2, C12.2, C13.2, C14.2, C15.2, C16.2, C17.2, C18.2, C20.2, C21.2, C25.1, C27.2, C31.1, C32.2, C33.2, C34.1, C37.1, C38.2, C39.2, C40.2, C42.2, D2.2, IC2.2, IC3.2, IC4.2, J1.2, J1.3, J2.1, J3.6, J4.4, J5.S, J6.S, J7.S, J8.S, J11.21, J11.22, J11.23, J11.24, JP2.2, JP3.2, JP3.3, R1.2, R4.2, R6.2, R19.1, R22.1, R25.2, R30.2, R31.2, R32.2, R33.2, R37.1, R38.1, R39.1, R40.2, R44.2, R46.2, R48.2, R50.2, R53.2, R54.2, R55.2, R56.2, R64.1, R73.2, U1.6, U1.18, U1.28, U1.39, U2.2, U4.15, U6.11, U7.4, U8.7
GNDD: C19.2, J12.21, J12.22, J12.23, J12.24, LCD1.1, LED1.1, Q1.1, Q2.1, R10.1, SW2.2, SW3.2, SW4.2, SW5.2, U3.7, VR1.1, VR2.1, VR3.1, VR4.3
unnamed: C3.1, C4.1, D1.2, IC1.2, R2.2
unnamed: C5.1, D1.1, D2.1, IC5.1, IC5.2, IC5.3, R63.1, R65.1, S1.2, S1.3
unnamed: C15.1, U1.8, XTAL1.1
unnamed: C16.1, U1.7, XTAL1.2
unnamed: C21.1, R17.1, R20.2
unnamed: C22.1, R14.1
unnamed: C23.1, R15.1
unnamed: C24.1, J5.R, J5.T, R17.2
unnamed: C24.2, R21.2, R22.2, U2.1
unnamed: C25.2, U4.6
unnamed: C26.2, U4.2
unnamed: C27.1, R27.2
unnamed: C28.1, U4.1
unnamed: C28.2, U4.3
unnamed: C29.1, U4.4
unnamed: C29.2, U4.5
unnamed: C30.2, R29.2
unnamed: C35.2, R30.1, U6.5
unnamed: C36.2, R16.1, R31.1, U6.3
unnamed: C41.1, U5.5
unnamed: C41.2, C45.2, C49.2, R67.1, R72.2, U5.7, U5.12
unnamed: C43.1, Q4.1, R57.1
unnamed: C44.1, Q7.1, R58.1
unnamed: C45.1, U5.6
unnamed: C46.1, C47.1, C48.1, C49.1, IC6.1, IC6.2, IC6.3, J2.2, J13.1, R68.1, U5.16
unnamed: C46.2, R68.2, U5.15
unnamed: C47.2, R69.2, U5.14
unnamed: C48.2, R70.2, U5.13
unnamed: D3.2, R34.1, U6.7, U6.10
unnamed: D4.2, R35.1, U6.1, U6.12
unnamed: IC1.1, R1.1, R2.1
unnamed: IC5.4, R65.2, U5.1
unnamed: IC5.5, IC5.6, IC5.7, IC5.8, IC6.5, IC6.6, IC6.7, IC6.8
unnamed: IC6.4, R66.1
unnamed: J4.2, R25.1, R26.2
unnamed: J4.3, U4.10
unnamed: J6.R, R15.2
unnamed: J6.RN, JP3.4
unnamed: J6.T, R14.2
unnamed: J6.TN, JP3.1
unnamed: J7.R, R18.1, R19.2
unnamed: J7.T, R16.2
unnamed: J8.R, U4.13
unnamed: J8.RN, U4.7
unnamed: J8.T, U4.14
unnamed: J8.TN, U4.8
unnamed: J9.R, JP4.1
unnamed: J9.S, TR1.1
unnamed: J9.T, TR1.3
unnamed: J10.R, JP5.1
unnamed: J10.S, TR2.1
unnamed: J10.T, TR2.3
unnamed: J13.2, R69.1
unnamed: J13.3, R70.1
unnamed: J13.4, R71.1, R72.1, R73.1
unnamed: JP4.2, TR1.2
unnamed: JP5.2, TR2.2
unnamed: LCD1.2, VR4.2
unnamed: LCD1.A, R11.2
unnamed: LCD1.K, Q2.3
unnamed: LED1.2, R7.2
unnamed: LED2.2, R8.2
unnamed: LED3.2, R9.2
unnamed: LED4.1, R10.2
unnamed: Q1.2, R12.2
unnamed: Q1.3, Q2.2, R13.1
unnamed: Q3.1, R59.1
unnamed: Q3.2, TR1.6
unnamed: Q4.2, TR1.5
unnamed: Q5.1, R60.1
unnamed: Q5.2, TR1.4
unnamed: Q6.1, R61.1
unnamed: Q6.2, TR2.6
unnamed: Q7.2, TR2.5
unnamed: Q8.1, R62.1
unnamed: Q8.2, TR2.4
unnamed: R3.2, R4.1, U1.35
unnamed: R5.1, R6.1, U1.34
unnamed: R26.1, U4.9
unnamed: R27.1, R28.2, U2.3
unnamed: R28.1, R29.1, U2.4
unnamed: R32.1, R34.2, U6.6
unnamed: R33.1, R35.2, U6.2
unnamed: R36.1, R37.2, U6.9, U6.13
unnamed: R41.1, R43.2, R44.1, U7.5
unnamed: R41.2, U8.8
unnamed: R42.1, R45.2, R46.1, U7.3
unnamed: R42.2, U8.5
unnamed: R47.2, R48.1, R52.2, U7.6
unnamed: R49.2, R50.1, R51.2, U7.2
unnamed: R51.1, R57.2, U7.1
unnamed: R52.1, R58.2, U7.7
unnamed: R63.2, U5.2
unnamed: R64.2, U5.4
unnamed: R66.2, U5.3
unnamed: R67.2, U5.10
unnamed: R71.2, U5.11
unnamed: SW2.1, U3.1
unnamed: SW3.1, U3.4
unnamed: SW4.1, U3.8
unnamed: SW5.1, U3.11
PA0: Q3.3, Q5.3, Q6.3, Q8.3, R40.1, U1.37
PA1: C32.1, C35.1, J11.5, U1.36
PA1-PANEL: J12.5, VR1.2
PA4: J11.9, U1.33
PA4-PANEL: J12.9, VR2.2
PA5: J11.11, U1.32
PA5-PANEL: J12.11, VR3.2
PA6: C39.1, D4.1, R39.2, U1.31
PA7: C38.1, D3.1, R38.2, U1.30
PB0: R55.1, R61.2, U1.40
PB1: R56.1, R62.2, U1.41
PB2: R53.1, R59.2, U1.42
PB3: R54.1, R60.2, U1.43
PB5: J3.4, U1.1, U8.3
PB6: J3.1, U1.2
PB7: J3.3, U1.3, U8.2
PC0: J11.2, U1.19
PC0-PANEL: J12.2, U3.5, U3.6, U3.12, U3.13
PC1: J11.4, U1.20
PC1-PANEL: J12.4, LCD1.5
PC2: J11.6, U1.21
PC2-PANEL: J12.6, LCD1.6
PC3: J11.8, U1.22
PC3-PANEL: J12.8, LCD1.4
PC4: J11.10, U1.23
PC4-PANEL: J12.10, LCD1.11, U3.2
PC5: J11.12, U1.24
PC5-PANEL: J12.12, LCD1.12, U3.3
PC6: J11.14, U1.25
PC6-PANEL: J12.14, LCD1.13, U3.9
PC7: J11.16, U1.26
PC7-PANEL: J12.16, LCD1.14, U3.10
PD0: U1.9, U4.12
PD1: U1.10, U4.11
PD2: U1.11, U6.14
PD3: U1.12, U6.8
PD5: J11.15, U1.14
PD5-PANEL: J12.15, LED2.1
PD6: J11.13, U1.15
PD6-PANEL: J12.13, LED3.1
PD7: J11.18, U1.16
PD7-PANEL: J12.18, R12.1
RB4: C33.1, C36.1, J11.7
RB4-PANEL: J12.7, VR1.4
RB9: C23.2, C30.1, J11.3, R24.1
RB9-PANEL: J12.3, VR1.5
RB10: C22.2, J11.1, R23.2
RB10-PANEL: J12.1, VR1.3
STATE: J4.1, J11.17
STATE-PANEL: J12.17, LED4.2
~CS: U1.13, U8.1
~RESET: J3.5, U1.4

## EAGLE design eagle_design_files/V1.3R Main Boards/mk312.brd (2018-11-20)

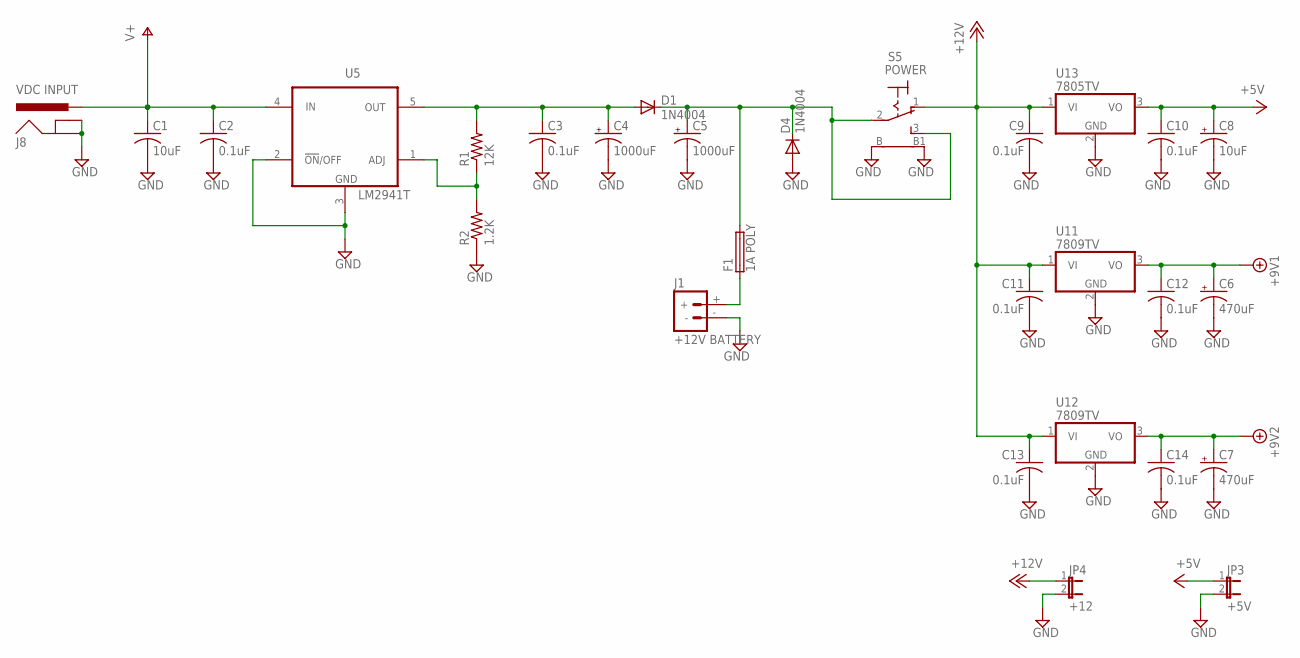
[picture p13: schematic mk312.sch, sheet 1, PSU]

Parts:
C1: 10uF; C050-024X044
C2, C3, C9, C10, C11, C12, C13, C14: 0.1uF; C025-024X044
C4, C5: 1000uF; E5-10,5
C6, C7: 470uF; E3,5-8
C8: 10uF; E2,5-7
D1, D4: 1N4004; DO41-10
F1: 1A POLY; LITTLEFUSE
J1: +12V BATTERY; DEANS
J8: VDC INPUT; POWER_JACK_SLOT
JP3: +5V; JP1
JP4: +12; JP1
R1: 12K; 0207/10
R2: 1.2K; 0207/10
S5: POWER; LPV-1
U5: LM2941T; TO220-5
U11, U12: 7809TV; TO220V
U13: 7805TV; TO220V

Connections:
+5V: C8.+, C10.1, JP3.1, U13.3 (VO); also elsewhere on the board
+8V: C6.+, C12.1, U11.3 (VO); also elsewhere on the board
+9V: C7.+, C14.1, U12.3 (VO); also elsewhere on the board
+12V: C9.1, C11.1, C13.1, JP4.1, S5.1 (O), U11.1 (VI), U12.1 (VI), U13.1 (VI); also elsewhere on the board
GND: C1.2, C2.2, C3.2, C4.-, C5.-, C6.-, C7.-, C8.-, C9.2, C10.2, C11.2, C12.2, C13.2, C14.2, D4.A, J1.-, J8.GND@1 (GNDBREAK), J8.GND@2 (GND), JP3.2, JP4.2, R2.1, S5.B, S5.B1, U5.2 (!ON!/OFF), U5.3 (GND), U11.2 (GND), U12.2 (GND), U13.2 (GND); also elsewhere on the board
unnamed: F1.1, J1.+
unnamed: R1.1, R2.2, U5.1 (ADJ)
unnamed: C3.1, C4.+, D1.A, R1.2, U5.5 (OUT)
unnamed: C5.+, D1.C, D4.C, F1.2, S5.2, S5.3 (S)
V+: C1.1, C2.1, J8.PWR, U5.4 (IN); also elsewhere on the board

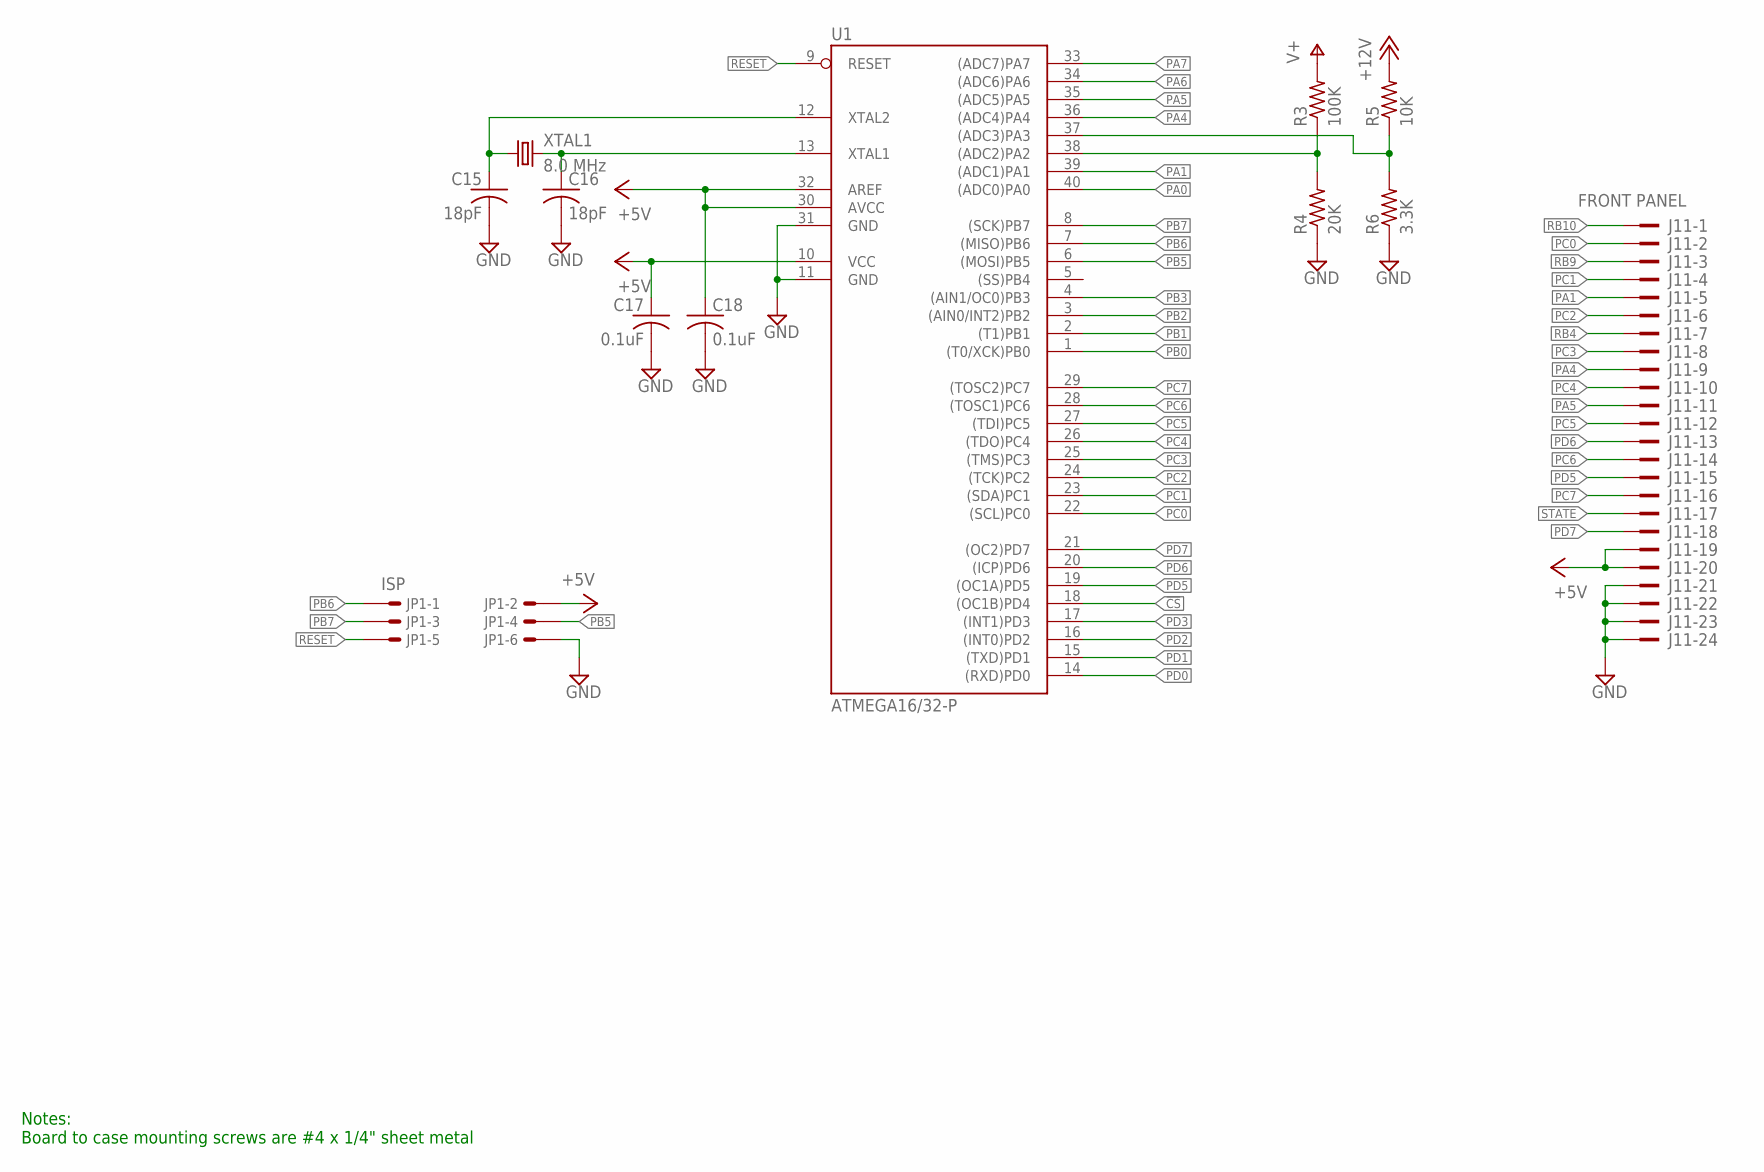
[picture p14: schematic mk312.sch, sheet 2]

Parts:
C15, C16: 18pF; C025-024X044
C17, C18: 0.1uF; C025-024X044
J11: FRONT PANEL; PAK100/2500-24
JP1: ISP; 057-006-1
R3: 100K; 0207/10
R4: 20K; 0207/10
R5: 10K; 0207/10
R6: 3.3K; 0207/10
U1: ATMEGA16/32-P; DIL40
XTAL1: 8.0 MHz; HC49/S

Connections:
!CS: U1.18 ((OC1B)PD4); also elsewhere on the board
+5V: C17.1, C18.1, J11.19, J11.20, JP1.2, U1.10 (VCC), U1.30 (AVCC), U1.32 (AREF); also elsewhere on the board
+12V: R5.2; also elsewhere on the board
GND: C15.2, C16.2, C17.2, C18.2, J11.21, J11.22, J11.23, J11.24, JP1.6, R4.1, R6.1, U1.11 (GND), U1.31 (GND); also elsewhere on the board
unnamed: R5.1, R6.2, U1.37 ((ADC3)PA3)
unnamed: R3.1, R4.2, U1.38 ((ADC2)PA2)
unnamed: C16.1, U1.13 (XTAL1), XTAL1.2
unnamed: C15.1, U1.12 (XTAL2), XTAL1.1
PA0: U1.40 ((ADC0)PA0); also elsewhere on the board
PA1: J11.5, U1.39 ((ADC1)PA1); also elsewhere on the board
PA4: J11.9, U1.36 ((ADC4)PA4)
PA5: J11.11, U1.35 ((ADC5)PA5)
PA6: U1.34 ((ADC6)PA6); also elsewhere on the board
PA7: U1.33 ((ADC7)PA7); also elsewhere on the board
PB0: U1.1 ((T0/XCK)PB0); also elsewhere on the board
PB1: U1.2 ((T1)PB1); also elsewhere on the board
PB2: U1.3 ((AIN0/INT2)PB2); also elsewhere on the board
PB3: U1.4 ((AIN1/OC0)PB3); also elsewhere on the board
PB5: JP1.4, U1.6 ((MOSI)PB5); also elsewhere on the board
PB6: JP1.1, U1.7 ((MISO)PB6)
PB7: JP1.3, U1.8 ((SCK)PB7); also elsewhere on the board
PC0: J11.2, U1.22 ((SCL)PC0); also elsewhere on the board
PC1: J11.4, U1.23 ((SDA)PC1); also elsewhere on the board
PC2: J11.6, U1.24 ((TCK)PC2); also elsewhere on the board
PC3: J11.8, U1.25 ((TMS)PC3); also elsewhere on the board
PC4: J11.10, U1.26 ((TDO)PC4); also elsewhere on the board
PC5: J11.12, U1.27 ((TDI)PC5); also elsewhere on the board
PC6: J11.14, U1.28 ((TOSC1)PC6); also elsewhere on the board
PC7: J11.16, U1.29 ((TOSC2)PC7); also elsewhere on the board
PD0: U1.14 ((RXD)PD0); also elsewhere on the board
PD1: U1.15 ((TXD)PD1); also elsewhere on the board
PD2: U1.16 ((INT0)PD2); also elsewhere on the board
PD3: U1.17 ((INT1)PD3); also elsewhere on the board
PD5: J11.15, U1.19 ((OC1A)PD5); also elsewhere on the board
PD6: J11.13, U1.20 ((ICP)PD6); also elsewhere on the board
PD7: J11.18, U1.21 ((OC2)PD7); also elsewhere on the board
RB4: J11.7; also elsewhere on the board
RB9: J11.3; also elsewhere on the board
RB10: J11.1; also elsewhere on the board
RESET: JP1.5, U1.9 (RESET)
STATE: J11.17; also elsewhere on the board
V+: R3.2; also elsewhere on the board

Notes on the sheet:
Notes: Board to case mounting screws are #4 x 1/4" sheet metal

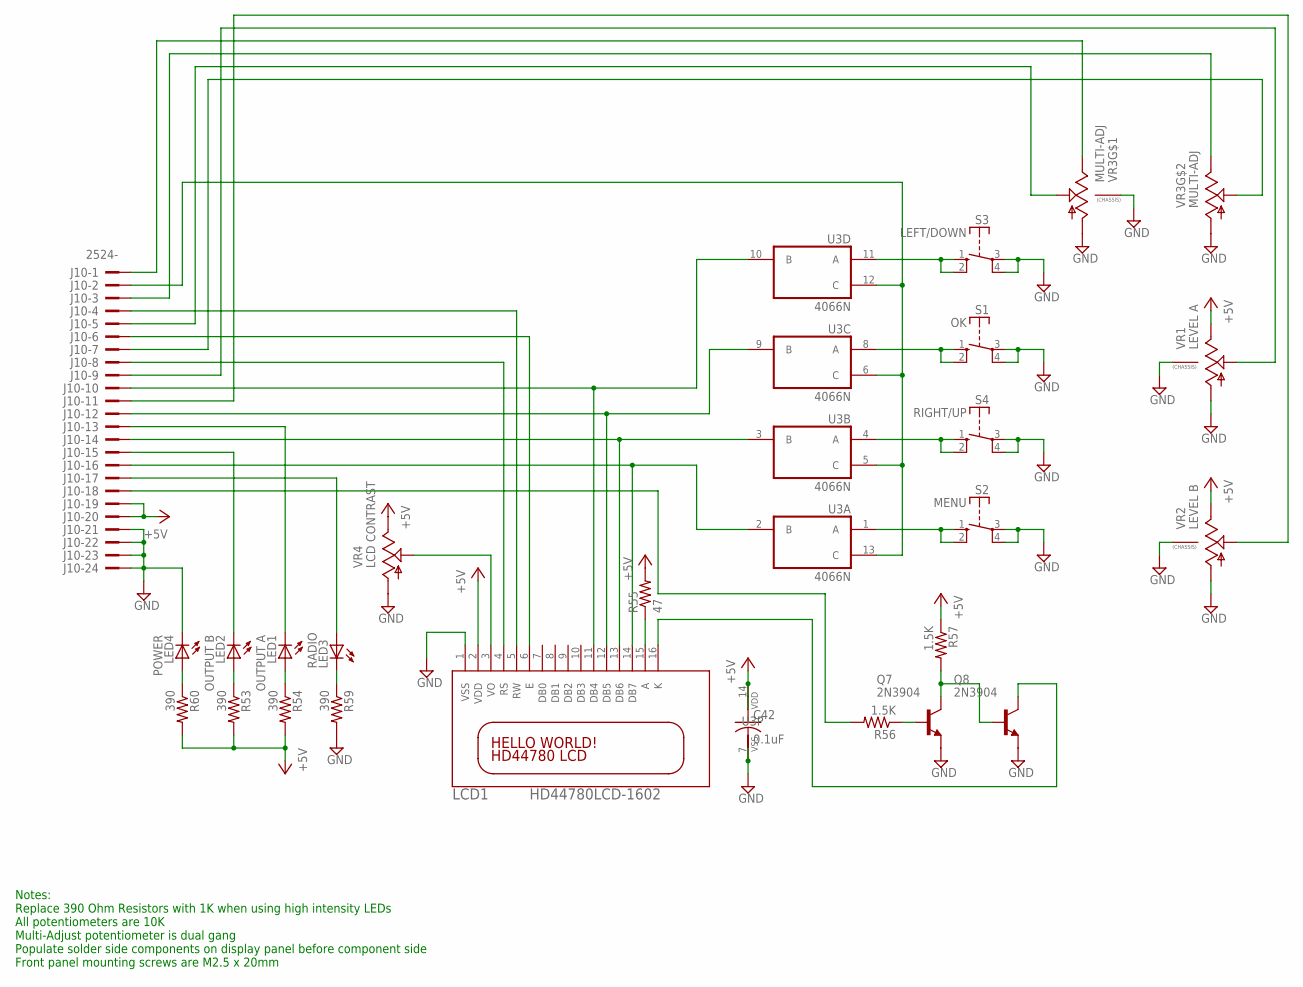
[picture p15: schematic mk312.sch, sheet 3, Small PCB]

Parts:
C42: 0.1uF; C025-024X044
J10: 2524-; PAK100/2500-24
LCD1: HD44780LCD-1602; LCD1602
LED1: OUTPUT A; LED5MM
LED2: OUTPUT B; LED5MM
LED3: RADIO; LED5MM
LED4: POWER; LED5MM
Q7, Q8: 2N3904; TO92
R53, R54, R59, R60: 390; 0207/10
R55: 47; 0207/10
R56, R57: 1.5K; 0207/10
S1: OK; DTE6K
S2: MENU; DTE6K
S3: LEFT/DOWN; DTE6K
S4: RIGHT/UP; DTE6K
U3: 4066N; DIL14
VR1: LEVEL A; 9MM_SNAP-IN_POT
VR2: LEVEL B; 9MM_SNAP-IN_POT
VR3: MULTI-ADJ; DUAL_9MM_SNAP-IN_POT
VR4: LCD CONTRAST; B25P

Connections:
+5V: C42.1, J10.19, J10.20, LCD1.2 (VDD), R53.2, R54.2, R55.2, R57.1, R60.2, U3.14 (VDD), VR1.3 (E), VR2.3 (E), VR4.E; also elsewhere on the board
GND: C42.2, J10.21, J10.22, J10.23, J10.24, LCD1.1 (VSS), LED4.K (C), Q7.3 (E), Q8.3 (E), R59.2, S1.3, S1.4, S2.3, S2.4, S3.3, S3.4, S4.3, S4.4, U3.7 (VSS), VR1.1 (A), VR1.CHASSIS2, VR2.1 (A), VR2.CHASSIS2, VR3.1 (A), VR3.1B (A), VR3.CHASSIS1, VR3.CHASSIS2, VR4.A; also elsewhere on the board
unnamed: J10.7, VR3.2B (S)
unnamed: S1.1 (S), S1.2 (S), U3.8 (A)
unnamed: S3.1 (S), S3.2 (S), U3.11 (A)
unnamed: S4.1 (S), S4.2 (S), U3.4 (A)
unnamed: J10.3, VR3.3B (E)
unnamed: J10.9, VR1.2 (S)
unnamed: J10.11, VR2.2 (S)
unnamed: J10.1, VR3.3 (E)
unnamed: J10.5, VR3.2 (S)
unnamed: LED2.A, R53.1
unnamed: LED1.A, R54.1
unnamed: LCD1.3 (VO), VR4.S
unnamed: LCD1.15 (A), R55.1
unnamed: LED3.K (C), R59.1
unnamed: S2.1 (S), S2.2 (S), U3.1 (A)
unnamed: LED4.A, R60.1
unnamed: Q7.2 (B), R56.1
unnamed: Q7.1 (C), Q8.2 (B), R57.2
unnamed: LCD1.16 (K), Q8.1 (C)
unnamed: J10.17, LED3.A
PC0: J10.2, U3.5 (C), U3.6 (C), U3.12 (C), U3.13 (C); also elsewhere on the board
PC1: J10.4, LCD1.5 (RW); also elsewhere on the board
PC2: J10.6, LCD1.6 (E); also elsewhere on the board
PC3: J10.8, LCD1.4 (RS); also elsewhere on the board
PC4: J10.10, LCD1.11 (DB4), U3.10 (B); also elsewhere on the board
PC5: J10.12, LCD1.12 (DB5), U3.9 (B); also elsewhere on the board
PC6: J10.14, LCD1.13 (DB6), U3.3 (B); also elsewhere on the board
PC7: J10.16, LCD1.14 (DB7), U3.2 (B); also elsewhere on the board
PD5: J10.15, LED2.K (C); also elsewhere on the board
PD6: J10.13, LED1.K (C); also elsewhere on the board
PD7: J10.18, R56.2; also elsewhere on the board

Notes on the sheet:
Notes: Replace 390 Ohm Resistors with 1K when using high intensity LEDs All potentiometers are 10K Multi-Adjust potentiometer is dual gang Populate solder side components on display panel before component side Front panel mounting screws are M2.5 x 20mm

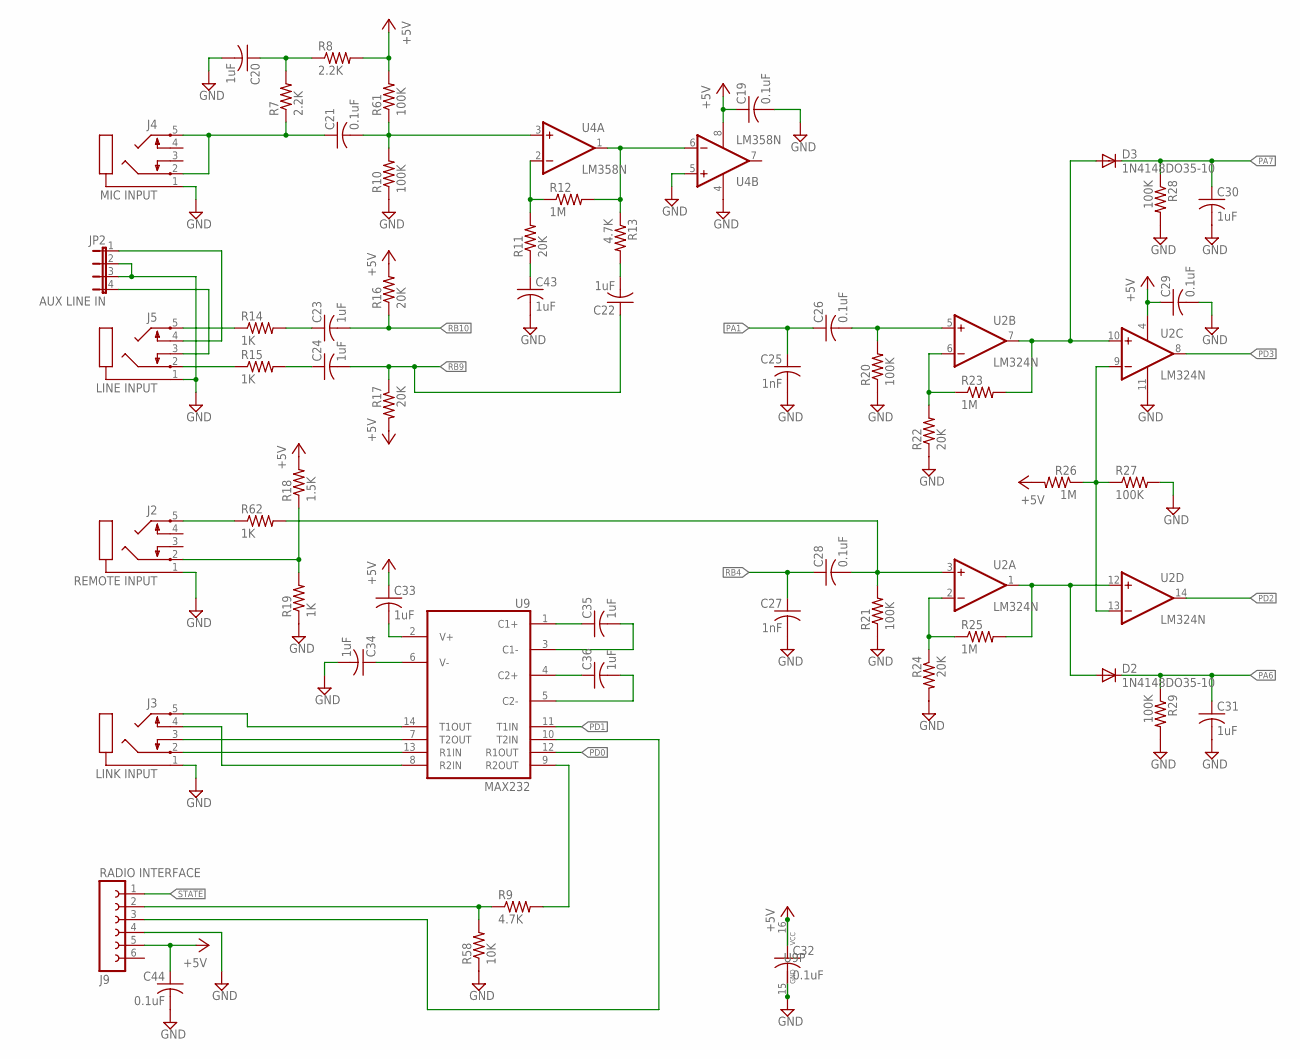
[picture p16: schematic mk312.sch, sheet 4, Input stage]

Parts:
C19, C21, C26, C28, C29, C32, C44: 0.1uF; C025-024X044
C20, C22, C23, C24, C30, C31, C33, C34, C35, C36, C43: 1uF; C025-024X044
C25, C27: 1nF; C025-024X044
D2, D3: 1N4148DO35-10; DO35-10
J2: REMOTE INPUT; STX3100
J3: LINK INPUT; STX3100
J4: MIC INPUT; STX3100
J5: LINE INPUT; STX3100
J9: RADIO INTERFACE; FE06
JP2: AUX LINE IN; JP4
R7, R8: 2.2K; 0207/10
R9, R13: 4.7K; 0207/10
R10, R20, R21, R27, R28, R29, R61: 100K; 0207/10
R11, R16, R17, R22, R24: 20K; 0207/10
R12, R23, R25, R26: 1M; 0207/10
R14, R15, R19, R62: 1K; 0207/10
R18: 1.5K; 0207/10
R58: 10K; 0207/10
U2: LM324N; DIL14
U4: LM358N; DIL08
U9: MAX232; DIL16

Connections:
+5V: C19.1, C29.1, C32.1, C33.1, C44.1, J9.5, R8.2, R16.2, R17.2, R18.2, R26.2, R61.2, U2.4 (V+), U4.8 (V+), U9.16 (VCC); also elsewhere on the board
GND: C19.2, C20.2, C25.2, C27.2, C29.2, C30.2, C31.2, C32.2, C34.2, C43.2, C44.2, J2.1, J3.1, J4.1, J5.1, J9.4, JP2.2, JP2.3, R10.1, R19.1, R20.1, R21.1, R22.1, R24.2, R27.2, R28.2, R29.2, R58.1, U2.11 (V-), U4.4 (V-), U4.5 (+IN), U9.15 (GND); also elsewhere on the board
unnamed: C28.2, R21.2, R62.2, U2.3 (+IN)
unnamed: R9.2, U9.9 (R2OUT)
unnamed: J3.5, U9.14 (T1OUT)
unnamed: J3.2, U9.13 (R1IN)
unnamed: C43.1, R11.1
unnamed: J2.5, R62.1
unnamed: C35.1, U9.1 (C1+)
unnamed: R24.1, R25.1, U2.2 (-IN)
unnamed: D2.A, R25.2, U2.1 (OUT), U2.12 (+IN)
unnamed: J5.2, R15.1
unnamed: J5.5, R14.1
unnamed: C23.1, R14.2
unnamed: J2.2, R18.1, R19.2
unnamed: J5.4, JP2.1
unnamed: R22.2, R23.1, U2.6 (-IN)
unnamed: C35.2, U9.3 (C1-)
unnamed: R26.1, R27.1, U2.9 (-IN), U2.13 (-IN)
unnamed: C26.2, R20.2, U2.5 (+IN)
unnamed: J5.3, JP2.4
unnamed: C24.1, R15.2
unnamed: C36.2, U9.5 (C2-)
unnamed: C36.1, U9.4 (C2+)
unnamed: J9.2, R9.1, R58.2
unnamed: D3.A, R23.2, U2.7 (OUT), U2.10 (+IN)
unnamed: C34.1, U9.6 (V-)
unnamed: C21.1, J4.2, J4.5, R7.1
unnamed: C20.1, R7.2, R8.1
unnamed: C21.2, R10.2, R61.1, U4.3 (+IN)
unnamed: R11.2, R12.1, U4.2 (-IN)
unnamed: R12.2, R13.1, U4.1 (OUT), U4.6 (-IN)
unnamed: C22.2, R13.2
unnamed: C33.2, U9.2 (V+)
unnamed: J3.4, U9.8 (R2IN)
unnamed: J3.3, U9.7 (T2OUT)
unnamed: J9.3, U9.10 (T2IN)
PA1: C25.1, C26.1; also elsewhere on the board
PA6: C31.1, D2.C, R29.1; also elsewhere on the board
PA7: C30.1, D3.C, R28.1; also elsewhere on the board
PD0: U9.12 (R1OUT); also elsewhere on the board
PD1: U9.11 (T1IN); also elsewhere on the board
PD2: U2.14 (OUT); also elsewhere on the board
PD3: U2.8 (OUT); also elsewhere on the board
RB4: C27.1, C28.1; also elsewhere on the board
RB9: C22.1, C24.2, R17.1; also elsewhere on the board
RB10: C23.2, R16.1; also elsewhere on the board
STATE: J9.1; also elsewhere on the board

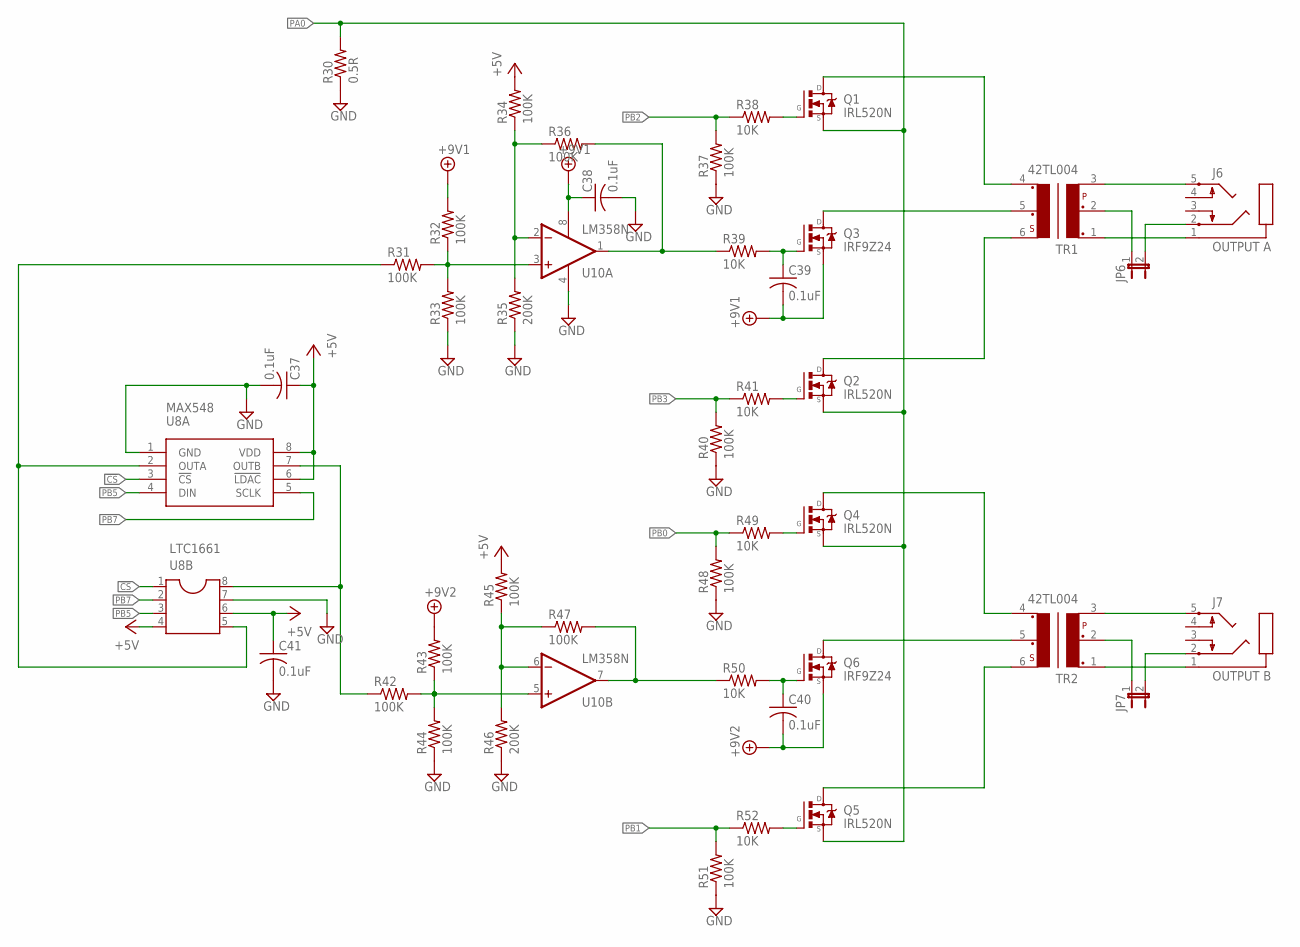
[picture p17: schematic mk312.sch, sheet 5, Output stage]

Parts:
C37, C38, C39, C40, C41: 0.1uF; C025-024X044
J6: OUTPUT A; STX3100
J7: OUTPUT B; STX3100
JP6, JP7: JP1E; JP1
Q1, Q2, Q4, Q5: IRL520N; TO220V
Q3, Q6: IRF9Z24; TO220V
R30: 0.5R; 0309/12
R31, R32, R33, R34, R36, R37, R40, R42, R43, R44, R45, R47, R48, R51: 100K; 0207/10
R35, R46: 200K; 0207/10
R38, R39, R41, R49, R50, R52: 10K; 0207/10
TR1, TR2: 42TL004; 42TL
U8A: MAX548; DIL08
U8B: LTC1661; SOCKET-08
U10: LM358N; DIL08

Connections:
!CS: U8A.3 (!CS), U8B.1; also elsewhere on the board
+5V: C37.1, C41.1, R34.2, R45.2, U8A.6 (!LDAC), U8A.8 (VDD), U8B.4, U8B.6; also elsewhere on the board
+8V: C38.1, C39.2, Q3.3 (S), R32.2, U10.8 (V+); also elsewhere on the board
+9V: C40.2, Q6.3 (S), R43.2; also elsewhere on the board
GND: C37.2, C38.2, C41.2, R30.1, R33.1, R35.1, R37.1, R40.1, R44.1, R46.1, R48.1, R51.1, U8A.1 (GND), U8B.7, U10.4 (V-); also elsewhere on the board
unnamed: Q3.2 (D), TR1.5
unnamed: Q6.2 (D), TR2.5
unnamed: JP7.1, TR2.2
unnamed: J6.1, TR1.1
unnamed: Q1.1 (G), R38.2
unnamed: Q2.1 (G), R41.2
unnamed: J7.2, JP7.2
unnamed: C39.1, Q3.1 (G), R39.2
unnamed: R31.2, R32.1, R33.2, U10.3 (+IN)
unnamed: Q4.1 (G), R49.2
unnamed: Q5.1 (G), R52.2
unnamed: J7.1, TR2.1
unnamed: C40.1, Q6.1 (G), R50.2
unnamed: R42.2, R43.1, R44.2, U10.5 (+IN)
unnamed: Q1.2 (D), TR1.4
unnamed: J6.5, TR1.3
unnamed: Q4.2 (D), TR2.4
unnamed: J7.5, TR2.3
unnamed: Q5.2 (D), TR2.6
unnamed: Q2.2 (D), TR1.6
unnamed: R34.1, R35.2, R36.1, U10.2 (-IN)
unnamed: R45.1, R46.2, R47.1, U10.6 (-IN)
unnamed: R31.1, U8A.2 (OUTA), U8B.5
unnamed: J6.2, JP6.2
unnamed: JP6.1, TR1.2
unnamed: R42.1, U8A.7 (OUTB), U8B.8
PA0: Q1.3 (S), Q2.3 (S), Q4.3 (S), Q5.3 (S), R30.2; also elsewhere on the board
PB0: R48.2, R49.1; also elsewhere on the board
PB1: R51.2, R52.1; also elsewhere on the board
PB2: R37.2, R38.1; also elsewhere on the board
PB3: R40.2, R41.1; also elsewhere on the board
PB5: U8A.4 (DIN), U8B.3; also elsewhere on the board
PB7: U8A.5 (SCLK), U8B.2; also elsewhere on the board
PFET_A: R36.2, R39.1, U10.1 (OUT)
PFET_B: R47.2, R50.1, U10.7 (OUT)

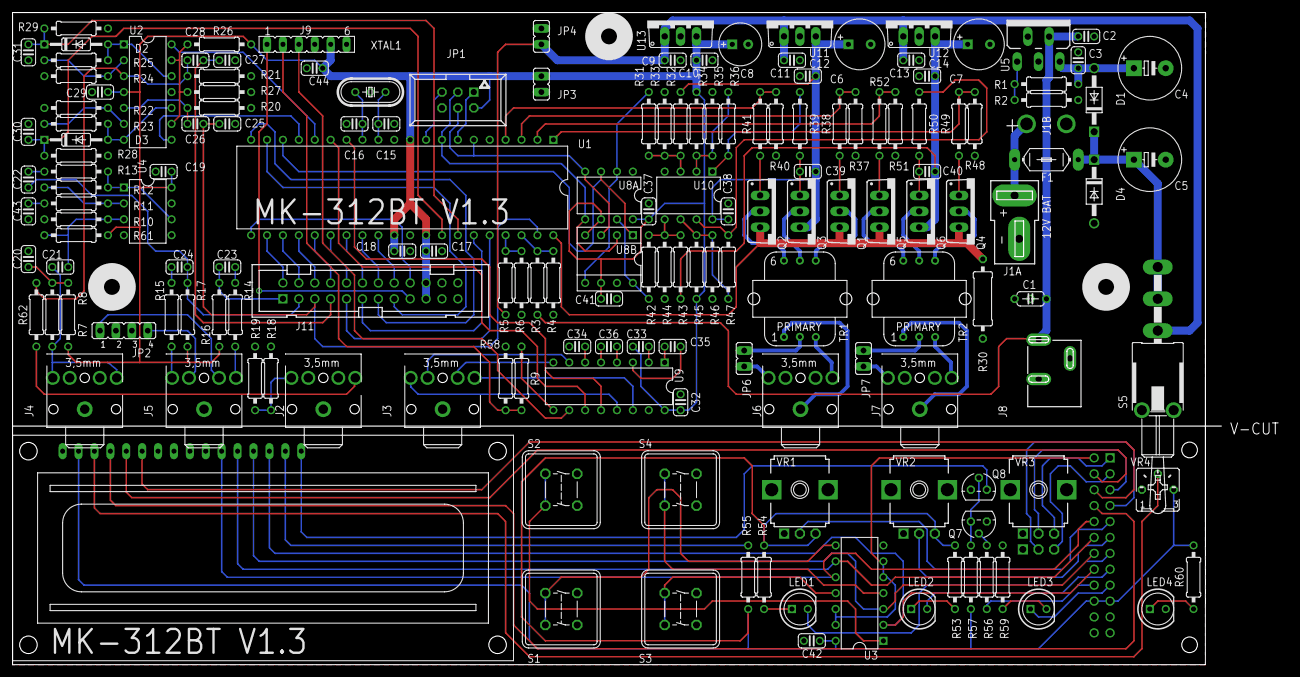
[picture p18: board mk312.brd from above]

Board: 2 copper layers, 193.0 x 104.1 mm, 165 parts (1 on the bottom side), 131 nets.

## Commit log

2018-11-11 Add v1.3 gerbers
    [copper_bottom.gbr, copper_top.gbr, drills.xln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]
2018-11-11 Move assembly instructions into README
2018-11-12 Remove v1.3 gerbers missing V-Cuts
    [copper_bottom.gbr, copper_top.gbr, drills.xln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]
2018-11-12 Fix Gerber 1.3 output using Seeed exporter in Eagle 9
    [gerber_job.gbrjob, mk312.GBL, mk312.GBO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]
2018-11-20 Update repo with V1.3 gerbers with value layers
    [MK-312BT V1.2.brd, MK-312BT V1.2.sch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]
2018-12-19 3d printable case.
    requires 4 M2.5x20, up to 3 M2.5x5, and some dampening for the battery.
    [case_v1.26.f3d, case_v1.26.stl, lid_v1.26.stl]
2018-12-19 Add 3D Printed case hardware instructions to README
2019-05-22 Kicad SMD version of mk312bt
    [Input_stage.sch, MK312B_MCU.sch, Output_stage.sch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]
2019-05-25 Case design, Kicad updates, part substitutions, etc
    [mk312-B_Cu.gbl, mk312-B_Mask.gbs, mk312-B_SilkS.gbo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]
2019-05-25 Added case design for smd version
    [Box.stl, Front_Faceplate.stl, Lid.stl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]
2019-05-25 Updated BOM, exported previews of PCB and schematic
    [bom.csv, mk312.csv]
2019-08-05 Firmware patch to support new LCD, more beefy power circuit for LiPo, added LiPo Balance and protection, fixed reversed op-amp comparitor pins
    [Output_stage.sch, PSU.sch, Panel_Circuit.sch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]

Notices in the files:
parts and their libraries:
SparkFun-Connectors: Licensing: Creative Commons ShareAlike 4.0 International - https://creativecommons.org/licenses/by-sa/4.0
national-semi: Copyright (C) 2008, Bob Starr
